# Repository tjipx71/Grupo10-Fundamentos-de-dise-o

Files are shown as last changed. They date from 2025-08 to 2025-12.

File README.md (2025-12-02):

# Equipo 10 - Fundamentos de Diseño 2025-2 
### Carrera de Ingeniería Ambiental / Informática   
**Universidad Peruana Cayetano Heredia**

---

## ENLACE DE DOCUMENTOS
https://docs.google.com/document/d/1tMh8w4P5lDI5NhleI3tkeHCaXAwBYwVb13Nxs4feQHg/edit?tab=t.0

## ENLACE DE ANTECEDENTES
LINK: https://docs.google.com/document/d/1iryDLKVLULV_mIBQmUCyinJf2zCzh2xDUNVw8ERWV84/edit?tab=t.qnuqcshna2gs

## ENLACE DE LISTA DE EXIGENCIAS
LINK: https://docs.google.com/document/d/1k8qPc2LVsW6A_ICCk7txNZ1e9gbutrCt8sIwpefmW50/edit?tab=t.0

## MODELADO 3D
LINK: https://cad.onshape.com/documents/656ee1c99e9142d88051f12c/w/5371e5df41db558604f3e5a4/e/c92471acf1fb395369bb92c8
---

## 🌍 Descripción del equipo

Somos participantes del curso **Fundamentos de Diseño 2025-2**, integrados por estudiantes de Ingeniería Ambiental y Informática. Nuestra misión es utilizar la metodología de diseño para desarrollar soluciones creativas que aporten valor social, tecnológico y ambiental.

En esta ocasión, hemos decidido centrar nuestro trabajo en el **Objetivo de Desarrollo Sostenible 6**: Agua limpia y saneamiento. Nos comprometemos a abordar desafíos relacionados con el acceso y la gestión responsable del agua, buscando generar un impacto positivo en nuestras comunidades y en el entorno natural.  

---

## Objetivo

Hacer el descarte de aguas posiblemente contaminadas con un dispositivo costo efectivo con lectura fácil y rápida, mostrando la categoría de los Estándares de Calidad del Agua para mejor comprensión y con una opción que describa los parámetros medidos. De esta manera se evita que la población use recursos hídricos comprometidos.

## Criterios de medición
- **pH:** Mide acidez/alcalinidad, clave para potabilidad y vida acuática.
- **Turbidez:** Indica partículas y posible presencia de patógenos.
- **Conductividad y salinidad:** Reflejan sales disueltas y riesgo para riego y consumo.
- **Temperatura:** Afecta solubilidad de oxígeno y actividad biológica.
- **Oxigeno disuelto:** Indican contaminación o exceso de materia orgánica en descomposición.

## Impacto esperado
- ***Social:*** Acceso a agua segura en comunidades vulnerables.
- ***Ambiental***: Reducción de enfermedades de origen hídrico y mejor control de la calidad del agua.
- ***Tecnológico:*** uso de sensores accesibles y plataformas digitales para monitoreo en tiempo real.

## Resultados esperados / métricas

- Conectar la información a un dashboard IoT.
- Posible escalabilidad hacia sistemas de alerta comunitaria o municipal
---

## 📷 Fotografía del equipo

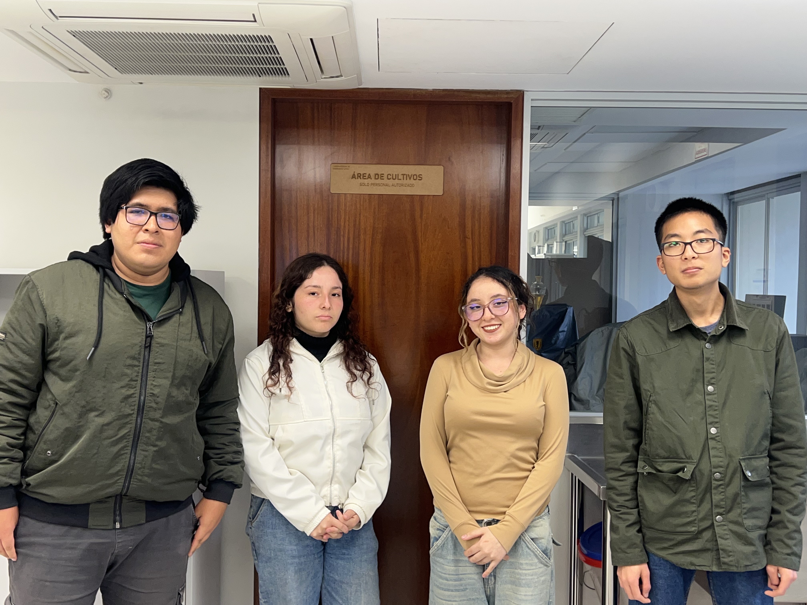
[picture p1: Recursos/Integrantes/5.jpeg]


---

## 👫 Integrantes

| Foto | Nombre | Rol | Intereses |
|---|---| --- | --- |
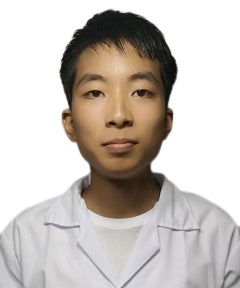
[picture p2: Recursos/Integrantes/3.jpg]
|  | **Karita John Kenneth** | **Líder / Diseñador** | **Diseño de prototipos, hardware** |
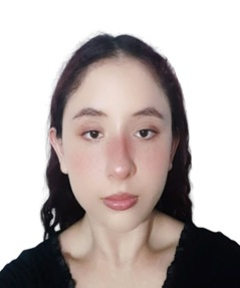
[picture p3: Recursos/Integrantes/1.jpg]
|  | **Belevan Amaro Bertha Dominik**|  **Responsable de investigación** | **Gestión ambiental, desarrollo comunitario** |
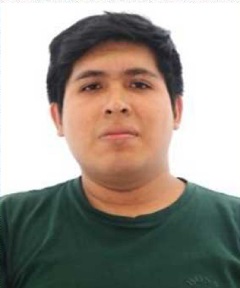
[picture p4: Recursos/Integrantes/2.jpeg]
|  | **Cctamayo Vasquez Willy Simeon** | **Programador / Modelador** | **Programación, simulación** |
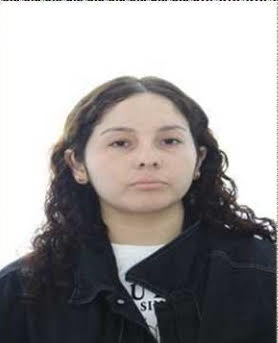
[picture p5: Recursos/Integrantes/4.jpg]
|  | **Vega Cuzcano Zulema Yamile** | **Encargado de Documentación** | **Producción de documentos científicos y técnicos** |

---

## 📚 Resumen Final
- Este README explica quiénes somos, qué nos motiva y cómo enfocamos nuestro trabajo en el **Objetivo de Desarrollo Sostenible 6: Agua limpia y saneamiento.** Somos un grupo comprometido con aprender y aportar soluciones para garantizar el acceso al agua potable y el saneamiento adecuado, fundamentales para la salud y el bienestar. Durante el curso, nuestro objetivo es contribuir a mejorar la gestión y uso sostenible del agua, buscando generar un impacto positivo en nuestra comunidad y el medio ambiente.

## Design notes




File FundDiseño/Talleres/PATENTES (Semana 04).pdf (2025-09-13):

OTRAS CATEGORÍAS

PARA SENSOR ESPECÍFICO

G01K - MEDICIÓN DE TEMPERATURA

G01R-27/22 medición de resistencia eléctrica de fluidos

G01Q-40/02 patrones de calibración

INTERPRETACIÓN DE DATOS

A62C-37/40 conexión eléctrica entre sensor y actuador

G01R-13/00 muestra de variables eléctricas

FUENTE DE PODER

E21B-47/017 protección de instrumentos

G01R-22/00 medidores de electricidad

G01R-1/03 circuitos de protección

TÍTULO | INSTRUMENTO PORTÁTIL DE MEDICIÓN DE LA CALIDAD DEL AGUA
SOLICITANTE(S) | | | FECHA DE PUBLICACIÓN
RESUMEN | | GRÁFICA/IMAGEN

BEIJING YONGCHENG TAMBIÉN CRÉDITO CIENCIA Y TECNOLOGÍA DESARROLLO SOCIEDAD LIMITADA

### 21 de junio de 2022

El modelo de utilidad pertenece al campo de los instrumentos de medición, y se refiere particularmente a un instrumento portátil de medición de calidad de agua que comprende una carcasa, un manguito antideslizante montado fijamente en un lado de la pared exterior de la carcasa, una primera ranura de fijación formada en el extremo superior de la pared exterior de la carcasa, un primer bloque de fijación conectado a la primera ranura de fijación, y un perno de fijación penetra a través del extremo superior del primer bloque de fijación; un extremo del perno de fijación está conectado con el mango; a través de la disposición del conjunto colorimétrico de muestra, una ranura de sujeción, un bloque de sujeción, una pantalla de filtro, una primera bisagra y una cubierta a prueba de polvo, se puede evitar que el líquido que se necesita medir se filtre aún más cuando el dispositivo se utiliza para la medición, se evita que las impurezas grandes entren en el dispositivo para influir en el resultado de la detección, y la pantalla de filtro se puede desmontar y limpiar después de un uso prolongado a través de la disposición de la ranura de sujeción y el bloque de sujeción, de modo que el dispositivo es cómodo de usar. Se prolonga la vida útil, se reduce el consumo de recursos y la primera bisagra y la cubierta a prueba de polvo están dispuestas de modo que el puerto de detección se puede proteger cuando el dispositivo no se utiliza y se evita que el polvo y otras impurezas ingresen al dispositivo para afectar el próximo uso.

CIP | G01N21/01, G01N21/78
LINK | https://worldwide.espacenet.com/patent/search/family/081998412/publication/CN216791993U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 water%20quality%20measuring%20instrument%22 (https://worldwide.espacenet.com/patent/search/family/081998412/publication/CN216791993U)

TITULO | Instrumento portátil de medición de la calidad del agua
SOLICITANTE(S) | | POINT FOUR WATER QUALITY TECHNOLOGIES SUZHOU CO LTDPOINT | FECHA DE PUBLICACIÓN
FOUR WATER QUALITY TECHNOLOGIES (SUZHOU) CO., LTD. 2012-01-04
RESUMEN | GRAFICA/IMAGEN

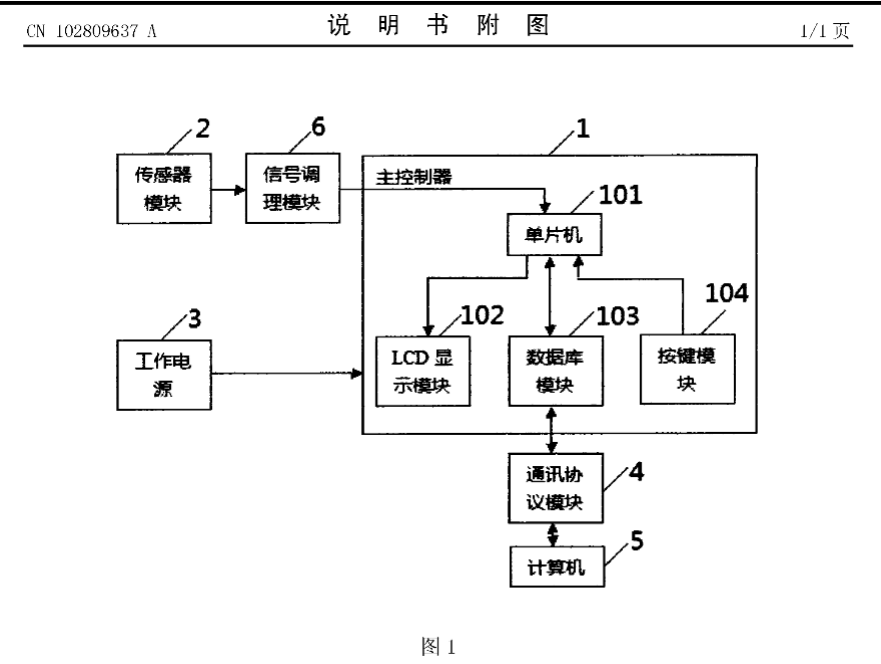
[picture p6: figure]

La invención describe un instrumento portátil de medición de la calidad del agua. El
instrumento portátil de medición de la calidad del agua comprende un controlador principal
conectado a una fuente de alimentación de funcionamiento, en donde el controlador principal comprende un solo chip y un módulo de base de datos, que están conectados entre sí; el módulo de base de datos está conectado a un módulo de protocolo de comunicación utilizado para comunicarse con una computadora; el solo chip está conectado a un módulo de modulación de señal; y el módulo de modulación de señal está conectado a un módulo de sensor. El módulo sensor incluye un sensor inteligente de conductividad/salinidad, un sensor inteligente de potencial de oxidación-reducción, un sensor inteligente de valor de pH, un sensor inteligente de gas disuelto total y un sensor inteligente de oxígeno disuelto. El instrumento portátil de medición de calidad de agua divulgado por la invención tiene las ventajas de alta precisión de medición, pequeño volumen y conveniencia para transportarlo y puede ser operado durante mucho tiempo; y los parámetros de medición de calidad de agua pueden almacenarse simultáneamente en el instrumento de medición de calidad de agua y en una computadora personal.
CIP | G01N33/18
LINK | https://worldwide.espacenet.com/patent/search/family/047233397/publication/CN102809637A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 water%20quality%20measuring%20instrument%22 (https://worldwide.espacenet.com/patent/search/family/047233397/publication/CN102809637A)

TITULO | Wireless water quality multi-parameter monitoring system
SOLICITANTE(S) | HANGZHOU ZONWON TECHNOLOGY CO LTDHANGZHOU ZONWON TECHNOLOGY CO., LTD. | FECHA DE PUBLICACION: 6 de Agosto 2014
RESUMEN | | GRAFICA/IMAGEN
La invención divulga un sistema inalámbrico de monitoreo multiparamétrico de calidad de agua que
consiste en un servidor, un terminal de usuario y una pluralidad de monitores inalámbricos
multiparamétricos de calidad de agua, en donde los monitores inalámbricos multiparamétricos de
calidad de agua están conectados con el servidor a través de una red de comunicación inalámbrica, y el terminal de usuario está conectado con el servidor a través de una red de comunicación cableada o inalámbrica; el software de gestión de datos y un módulo receptor inalámbrico están instalados en el servidor, y las baterías, las placas de circuitos de control, los módulos transmisores inalámbricos y los sensores de calidad de agua están instalados en las carcasas de los monitores inalámbricos multiparamétricos de calidad de agua. Según este sistema, no es necesario que un trabajador mida o tome muestras en el sitio, por lo que el costo de mano de obra se reduce en gran medida y, además, se pueden proporcionar datos en tiempo real, de modo que la calidad del agua se pueda dominar de manera conveniente y completa en tiempo real.
CIP | G01N33/18

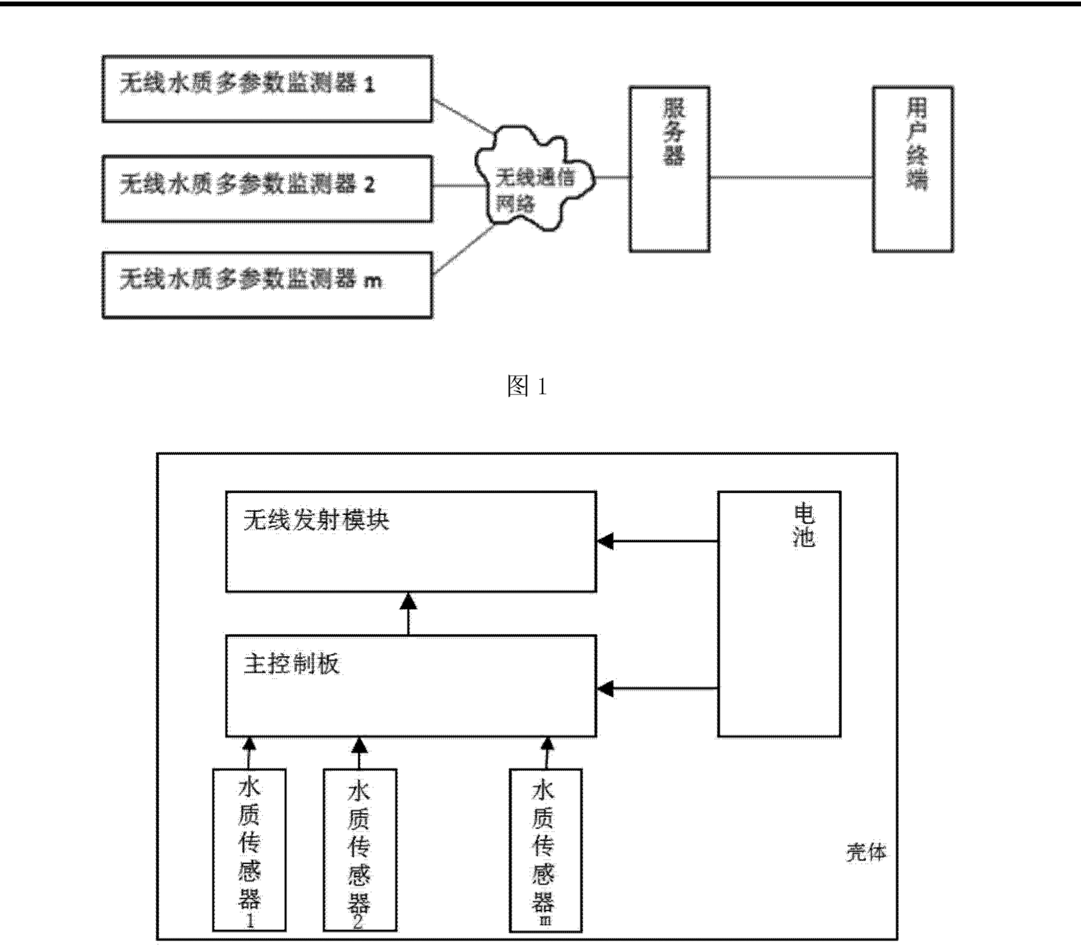
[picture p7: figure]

LINK | https://worldwide.espacenet.com/patent/search/family/051239164/publication/CN103969414A?q=ti%20all%20%22Wirele ss%20multi-parameter%20water-quality%20monitoring%20system%22 (https://worldwide.espacenet.com/patent/search/family/051239164/publication/CN103969414A)

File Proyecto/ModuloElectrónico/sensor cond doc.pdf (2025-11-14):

Documentación del sensor de conductividad

Para obtener el valor de una resistencia desconocida se le puede aplicar un voltaje conocido y éste como resultado tendrá un consumo medible. Debido a que los Convertidores Digitales Analógicos (ADC) no pueden medir intensidad, se le tiene que poner una resistencia de valor conocido en serie con la resistencia desconocida para poder formar un divisor de voltaje y con su salida calcular el valor de la resistencia que se desea saber.

Este mismo principio se utiliza para el sensor de conductividad del agua, puesto a que la conductividad es la inversa de la resistencia dividido por la distancia entre electrodos. Pero, tiene un detalle muy importante, el voltaje de medición tiene que ser alterna y su voltaje pulsante tiene que ser lo suficientemente bajo como para no alterar las propiedades del agua mediante electrólisis.

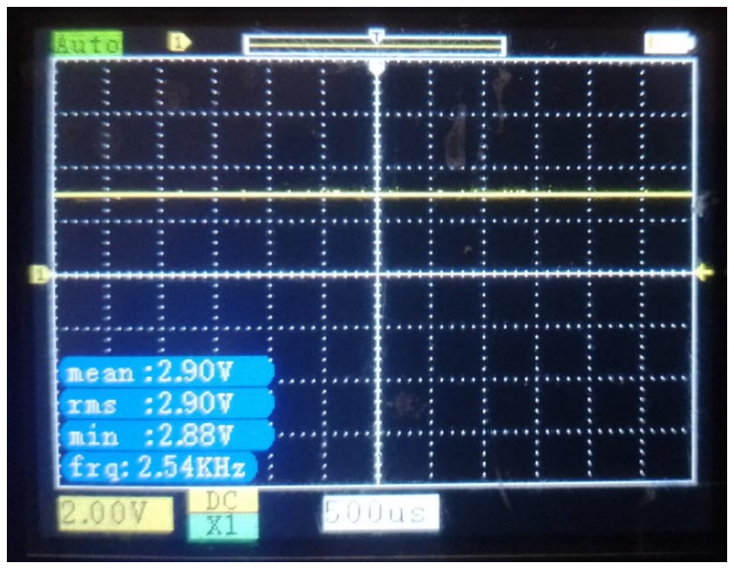
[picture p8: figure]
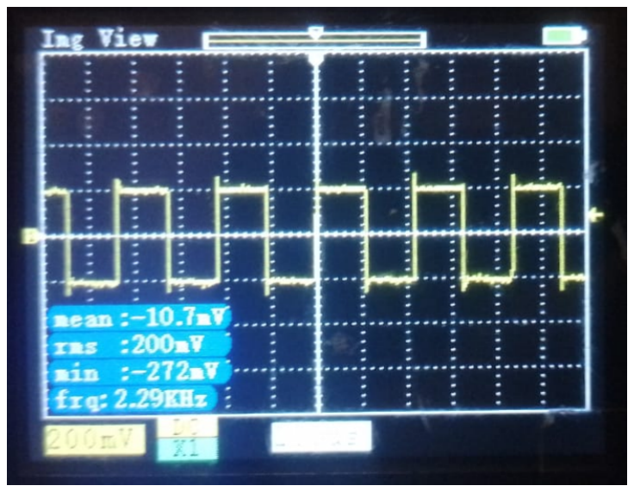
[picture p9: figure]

Multímetro | Sensor de TDS/Conductividad

Para lograr el primer efecto se puede utilizar un controlador que genere una señal, el problema viene cuando sus señales digitales son de 0V a 5V, no de -0.2V a 0.2V. Con el fin de resolver este problema, se podría utilizar un divisor de voltaje y un amplificador operacional configurado como seguidor de voltaje. Inmediatamente viene otro problema, la alimentación de 5V al controlador no ofrece voltajes negativos. Esto se puede solucionar utilizando un divisor de voltaje para obtener 2.5V y mandando su salida a un seguidor de voltaje para que éste ofrezca un voltaje de referencia al primer amplificador operacional. Con esto, se puede utilizar el primer amplificador operacional para generar 2.7V y 2.3V con respecto a GND, cuyas lecturas respecto al voltaje de referencia (2.5V) sería de 0.2V y -0.2V.

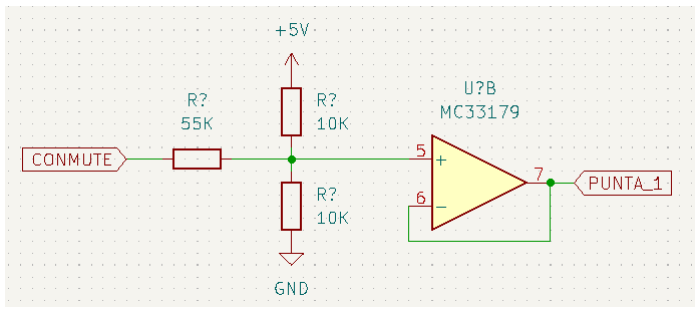
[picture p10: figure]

Generador de pulsos apoyado por microcontrolador en el pin “Conmutar”

Voltaje de referencia

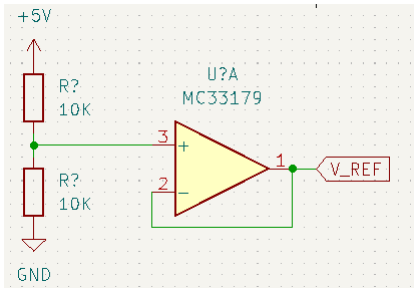
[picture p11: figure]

Teniendo ya la señal de pulsos que va a un electrodo y un voltaje de referencia, se puede medir construyendo un divisor de voltaje compuesto por una resistencia de valor conocido y el agua a medir, utilizando las señales previamente mencionadas. Debido a que la diferencia de potencial es mínima y se desea medir con buen precisión, éste debe amplificarse dentro del rango permitido de voltajes (-2.5V a 2.5V con respecto a referencia).

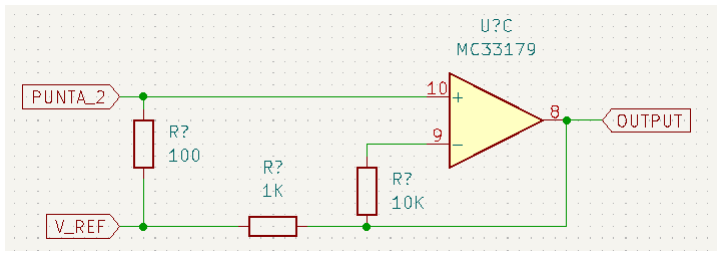
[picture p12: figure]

Nótese que la “punta 1” y “punta 2” son los pines de los electrodos que van al agua.

Para la lectura por parte de un microcontrolador, éste debe tener en cuenta los siguientes pines:

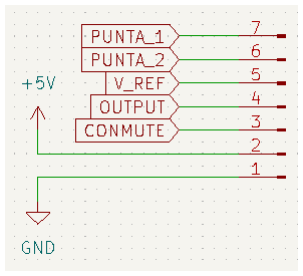
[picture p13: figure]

El código para leer la conductividad del agua para el controlador Arduino Nano:

#include <LiquidCrystal.h>

// LCD pins <--> Arduino pins

const | | int | RS = | 11, EN = | 12, D4 = | 2, D5 = | 3, D6 = | 4, D7 = | 5;
LiquidCrystal | lcd(RS, EN, D4, D5, D6, D7);
const | | float | r = | 100;
void | setup()
{
lcd.begin(16, | 2); | // set up number of columns and rows
pinMode(6, OUTPUT);
}
float | | leer(){
float | av_out = | analogRead(A0);
float | av_ref = | analogRead(A1);
float | av_pul = | analogRead(A2);
float | v_out = av_out/1023;
float | v_ref = av_ref/1023;
float | v_pul = av_pul/1023;
float | v_read = | (v_out - v_ref)/11;
float | v_pulse = v_pul - v_ref;
float | r_water = | (r * | (v_pulse - v_read)/v_read);
return | r_water;
}

void loop()
{
float | sum = | 0;
int | a = | 0;
while(a != | | | 500){
digitalWrite(6, HIGH);
sum = sum + | leer();
delayMicroseconds(500);
digitalWrite(6, LOW);
sum = sum + | leer();
delayMicroseconds(500);
a = a + | 1;
}
float | conductivity = | 0;
conductivity = | 1000000000 | / sum;

lcd.clear();
lcd.setCursor(0, | | | | 0);
lcd.print("Conductividad:");
lcd.setCursor(0, | | | | 1);
if(conductivity < | | 100){
lcd.print("< 100 uS");
} | else | | if | (conductivity > | 8000){

lcd.print("> 8000 uS");
} | else | if | (100 | <= conductivity and conductivity <= | 8000){
lcd.print(conductivity);
lcd.print(" uS");
} | else | {
lcd.print("Averiado");
}
}

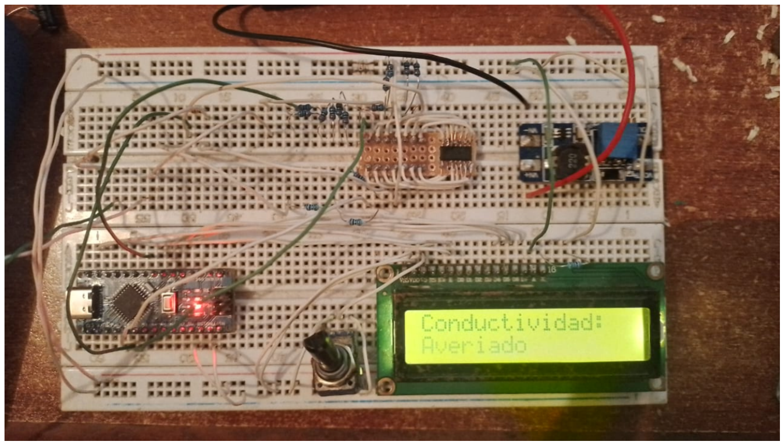
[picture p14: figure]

Construcción en placa de prototipo, el MC33179 fue adaptado de SMD a THT.

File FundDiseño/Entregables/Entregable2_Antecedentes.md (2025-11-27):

OTRAS CATEGORÍAS

PARA SENSOR ESPECÍFICO

G01K \- MEDICIÓN DE TEMPERATURA

G01R-27/22 medición de resistencia eléctrica de fluidos

G01Q-40/02 patrones de calibración

INTERPRETACIÓN DE DATOS

A62C-37/40 conexión eléctrica entre sensor y actuador

G01R-13/00 muestra de variables eléctricas

FUENTE DE PODER

E21B-47/017 protección de instrumentos

G01R-22/00 medidores de electricidad

G01R-1/03 circuitos de protección

| TÍTULO |  INSTRUMENTO PORTÁTIL DE MEDICIÓN DE LA CALIDAD DEL AGUA |  |
| :---- | ----- | ----- |
| **SOLICITANTE(S)** |  BEIJING YONGCHENG TAMBIÉN CRÉDITO CIENCIA Y TECNOLOGÍA DESARROLLO SOCIEDAD LIMITADA | **FECHA DE PUBLICACIÓN 21 de junio de 2022** |

| | |
| :---- | ----- |
| **RESUMEN** | **GRÁFICA/IMAGEN** |
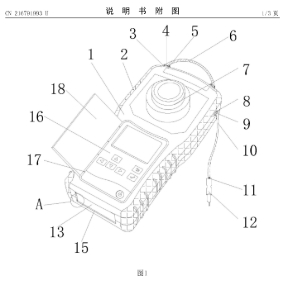
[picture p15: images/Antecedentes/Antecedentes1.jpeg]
|  El modelo de utilidad pertenece al campo de los instrumentos de medición, y se refiere particularmente a un instrumento portátil de medición de calidad de agua que comprende una carcasa, un manguito antideslizante montado fijamente en un lado de la pared exterior de la carcasa, una primera ranura de fijación formada en el extremo superior de la pared exterior de la carcasa, un primer bloque de fijación conectado a la primera ranura de fijación, y un perno de fijación penetra a través del extremo superior del primer bloque de fijación; un extremo del perno de fijación está conectado con el mango; a través de la disposición del conjunto colorimétrico de muestra, una ranura de sujeción, un bloque de sujeción, una pantalla de filtro, una primera bisagra y una cubierta a prueba de polvo, se puede evitar que el líquido que se necesita medir se filtre aún más cuando el dispositivo se utiliza para la medición, se evita que las impurezas grandes entren en el dispositivo para influir en el resultado de la detección, y la pantalla de filtro se puede desmontar y limpiar después de un uso prolongado a través de la disposición de la ranura de sujeción y el bloque de sujeción, de modo que el dispositivo es cómodo de usar. Se prolonga la vida útil, se reduce el consumo de recursos y la primera bisagra y la cubierta a prueba de polvo están dispuestas de modo que el puerto de detección se puede proteger cuando el dispositivo no se utiliza y se evita que el polvo y otras impurezas ingresen al dispositivo para afectar el próximo uso. |  |
| **CIP** | G01N21/01, G01N21/78 |

| | |
| :---- | ----- |
| **LINK** | [https://worldwide.espacenet.com/patent/search/family/081998412/publication/CN216791993U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](https://worldwide.espacenet.com/patent/search/family/081998412/publication/CN216791993U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)  |

| TÍTULO | Instrumento portátil de medición de la calidad del agua |  |
| :---- | :---- | :---- |
| **SOLICITANTE(S)** | POINT FOUR WATER QUALITY TECHNOLOGIES SUZHOU CO LTDPOINT FOUR WATER QUALITY TECHNOLOGIES (SUZHOU) CO., LTD. | **FECHA DE PUBLICACIÓN** 2012-01-04 |

| | |
| :---- | ----- |
| **RESUMEN** |  | **GRÁFICA/IMAGEN** |
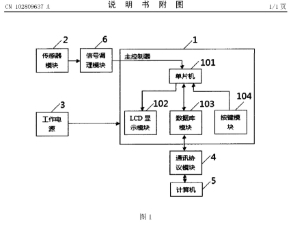
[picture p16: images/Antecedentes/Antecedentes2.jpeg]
|  La invención describe un instrumento portátil de medición de la calidad del agua. El instrumento portátil de medición de la calidad del agua comprende un controlador principal conectado a una fuente de alimentación de funcionamiento, en donde el controlador principal comprende un solo chip y un módulo de base de datos, que están conectados entre sí; el módulo de base de datos está conectado a un módulo de protocolo de comunicación utilizado para comunicarse con una computadora; el solo chip está conectado a un módulo de modulación de señal; y el módulo de modulación de señal está conectado a un módulo de sensor. El módulo sensor incluye un sensor inteligente de conductividad/salinidad, un sensor inteligente de potencial de oxidación-reducción, un sensor inteligente de valor de pH, un sensor inteligente de gas disuelto total y un sensor inteligente de oxígeno disuelto. El instrumento portátil de medición de calidad de agua divulgado por la invención tiene las ventajas de alta precisión de medición, pequeño volumen y conveniencia para transportarlo y puede ser operado durante mucho tiempo; y los parámetros de medición de calidad de agua pueden almacenarse simultáneamente en el instrumento de medición de calidad de agua y en una computadora personal.  |  |
| **CIP** | G01N33/18 .|  

| | |
| :---- | ----- |
| **LINK** | [https://worldwide.espacenet.com/patent/search/family/047233397/publication/CN102809637A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](https://worldwide.espacenet.com/patent/search/family/047233397/publication/CN102809637A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) |  

| TÍTULO | Wireless water quality multi-parameter monitoring system |  |
| :---- | :---- | :---- |
| **SOLICITANTE(S)** | HANGZHOU ZONWON TECHNOLOGY CO LTDHANGZHOU ZONWON TECHNOLOGY CO., LTD. | **FECHA DE PUBLICACIÓN: 6 de Agosto 2014** |

| | |
| :---- | ----- |
| **RESUMEN** |  | **GRÁFICA/IMAGEN** |
| La invención divulga un sistema inalámbrico de monitoreo multiparamétrico de calidad de agua que consiste en un servidor, un terminal de usuario y una pluralidad de monitores inalámbricos multiparamétricos de calidad de agua, en donde los monitores inalámbricos multiparamétricos de calidad de agua están conectados con el servidor a través de una red de comunicación inalámbrica, y el terminal de usuario está conectado con el servidor a través de una red de comunicación cableada o inalámbrica; el software de gestión de datos y un módulo receptor inalámbrico están instalados en el servidor, y las baterías, las placas de circuitos de control, los módulos transmisores inalámbricos y los sensores de calidad de agua están instalados en las carcasas de los monitores inalámbricos multiparamétricos de calidad de agua. Según este sistema, no es necesario que un trabajador mida o tome muestras en el sitio, por lo que el costo de mano de obra se reduce en gran medida y, además, se pueden proporcionar datos en tiempo real, de modo que la calidad del agua se pueda dominar de manera conveniente y completa en tiempo real.  |  |
| **CIP** | G01N33/18 .|  

| | |
| :---- | ----- |
| **LINK** | [https://worldwide.espacenet.com/patent/search/family/051239164/publication/CN103969414A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](https://worldwide.espacenet.com/patent/search/family/051239164/publication/CN103969414A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) |

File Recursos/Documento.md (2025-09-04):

ODS 6 : Agua limpia y saneamiento

El estudio sobre el monitoreo de la calidad del agua en un lago costero poco profundo destaca la aplicación de sistemas de información geográfica (SIG) junto con técnicas de análisis de decisiones multicriterio para mejorar significativamente la evaluación espacial de los parámetros ambientales. Esta combinación de herramientas permite un análisis más detallado y preciso de la distribución y variabilidad de la calidad del agua, facilitando una toma de decisiones más informada y efectiva para la gestión ambiental del ecosistema acuático. Así, el uso integrado de SIG y métodos multicriterio representa un avance importante en la planificación y conservación de cuerpos de agua sensibles, optimizando los recursos y promoviendo prácticas sostenibles. (1)

El propósito de investigar técnicas de análisis de decisiones multicriterio es observar las limitaciones de los sensores que posiblemente se añadan al proyecto (PH, sólidos disueltos, turbidez y conductividad) comparado a una situación ideal de medición. También, verificar los pesos de cada criterio y formular un posible índice tomando en cuenta los pocos parámetros que se pueden obtener sin sobrepasar el presupuesto.

El 33.33% de las mujeres evaluadas presentaron niveles elevados de mercurio en muestras de cabello, lo que indica una exposición significativa a este contaminante. Aunque no se encontró una correlación estadísticamente significativa entre la concentración de mercurio y la edad de las participantes, se observó que la mayoría de estas mujeres desempeñan labores domésticas y mantienen una dieta habitual basada en el consumo de pescado. Este patrón alimenticio sugiere que la principal vía de exposición al mercurio es a través de la ingesta continua de productos pesqueros, lo que pone en evidencia un riesgo crónico para la salud asociado a la acumulación de metales pesados provenientes del entorno ambiental y la cadena alimentaria. (2)

El estudio que desentraña y comprende las percepciones locales sobre la calidad del agua en la cuenca del Santa, Perú, resulta fundamental para captar cómo las comunidades perciben, valoran y responden a los riesgos asociados con la contaminación hídrica. Este enfoque sociocultural permite identificar barreras y oportunidades en la comunicación ambiental, facilitando así la implementación de estrategias más efectivas de prevención, educación y gestión del recurso hídrico, adaptadas a las realidades y necesidades locales. (3)

El estudio sobre la dinámica de la calidad del agua del río Cunas en zonas rurales y urbanas de la región central del Perú aporta datos valiosos y detallados acerca de las variaciones espaciales y temporales de los parámetros físico-químicos del agua. Esta información es fundamental para identificar diferencias significativas en los niveles de contaminación entre distintas áreas, lo que a su vez permite evaluar los posibles riesgos asociados para la salud humana y la integridad del ecosistema. Gracias a estos hallazgos, se pueden diseñar estrategias de gestión y mitigación más efectivas para proteger los recursos hídricos y garantizar un suministro seguro para las comunidades que dependen de este río.(4)

La Tabla 1 presenta los valores de concentración de indicadores fisicoquímicos —como pH, oxígeno disuelto, conductividad y sólidos totales— medidos en diferentes años en el río Cunas, Perú. Estos datos evidencian la variabilidad temporal en la calidad del agua y permiten identificar posibles riesgos para la salud pública y el ambiente. (5)

El estudio sobre acuicultura sostenible presenta un sistema integrado basado en tecnologías IoT que permite el monitoreo en tiempo real de la calidad del agua. Gracias al uso de sensores avanzados para medir parámetros críticos como el oxígeno disuelto y el amoníaco, este sistema facilita una gestión eficiente y oportuna, mejorando el control de las condiciones ambientales necesarias para el desarrollo saludable de los cultivos acuícolas. (6)

La revisión sobre contaminación del agua y evaluación de parámetros de calidad ofrece una visión clara de los principales indicadores físico-químicos usados para evaluar el estado de los cuerpos de agua. Permite entender tanto los niveles de contaminantes como su impacto en la salud ecológica y humana. Además, destaca la importancia de monitorear continuamente variables como pH, oxígeno disuelto, conductividad y sólidos totales, información clave para la toma de decisiones ambientales y el manejo sostenible de los recursos hídricos.(7)

Referencias	

1.	Batina A, Šiljeg A. Enhancing water quality monitoring in a coastal shallow lake using GIS and multi-criteria decision analysis. Environ Sustain Indic. diciembre de 2025;28:100881. 
2.	Grandez-Urbina JA, Gonzalo-Rodríguez J, Ronceros-Mayorga V, Bedoya-Vidal S, Grandez-Castillo G, Pérez-Zárate C. Concentración de mercurio en cabello de mujeres en una comunidad nativa de Perú. Gac Sanit. 1 de marzo de 2014;28(2):177. 
3.	Rangecroft S, Dextre RM, Richter I, Grados Bueno CV, Kelly C, Turin C, et al. Unravelling and understanding local perceptions of water quality in the Santa basin, Peru. J Hydrol. 1 de octubre de 2023;625:129949. 
4.	Custodio M, Peñaloza R, Chanamé F, Hinostroza-Martínez JL, De la Cruz H. Water quality dynamics of the Cunas River in rural and urban areas in the central region of Peru. Egypt J Aquat Res. 1 de septiembre de 2021;47(3):253-9. 
5.	Data on the spatial and temporal variability of physical-chemical water quality indicators of the Cunas River, Peru. Chem Data Collect. 1 de junio de 2021;33:100672. 
6.	Zuhaer A, Khandoker A, Enayet N, Partha PKP, Awal MdA. Sustainable Aquaculture: An IoT-Integrated System for Real-Time Water Quality Monitoring Featuring Advanced DO and Ammonia Sensors. Aquac Eng. 2 de septiembre de 2025;102620. 
7.	Water pollution and the assessment of water quality parameters: a review. Desalination Water Treat. 1 de mayo de 2023;294:79-88.

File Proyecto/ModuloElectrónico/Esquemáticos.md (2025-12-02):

## ESQUEMÁTICO INICIAL
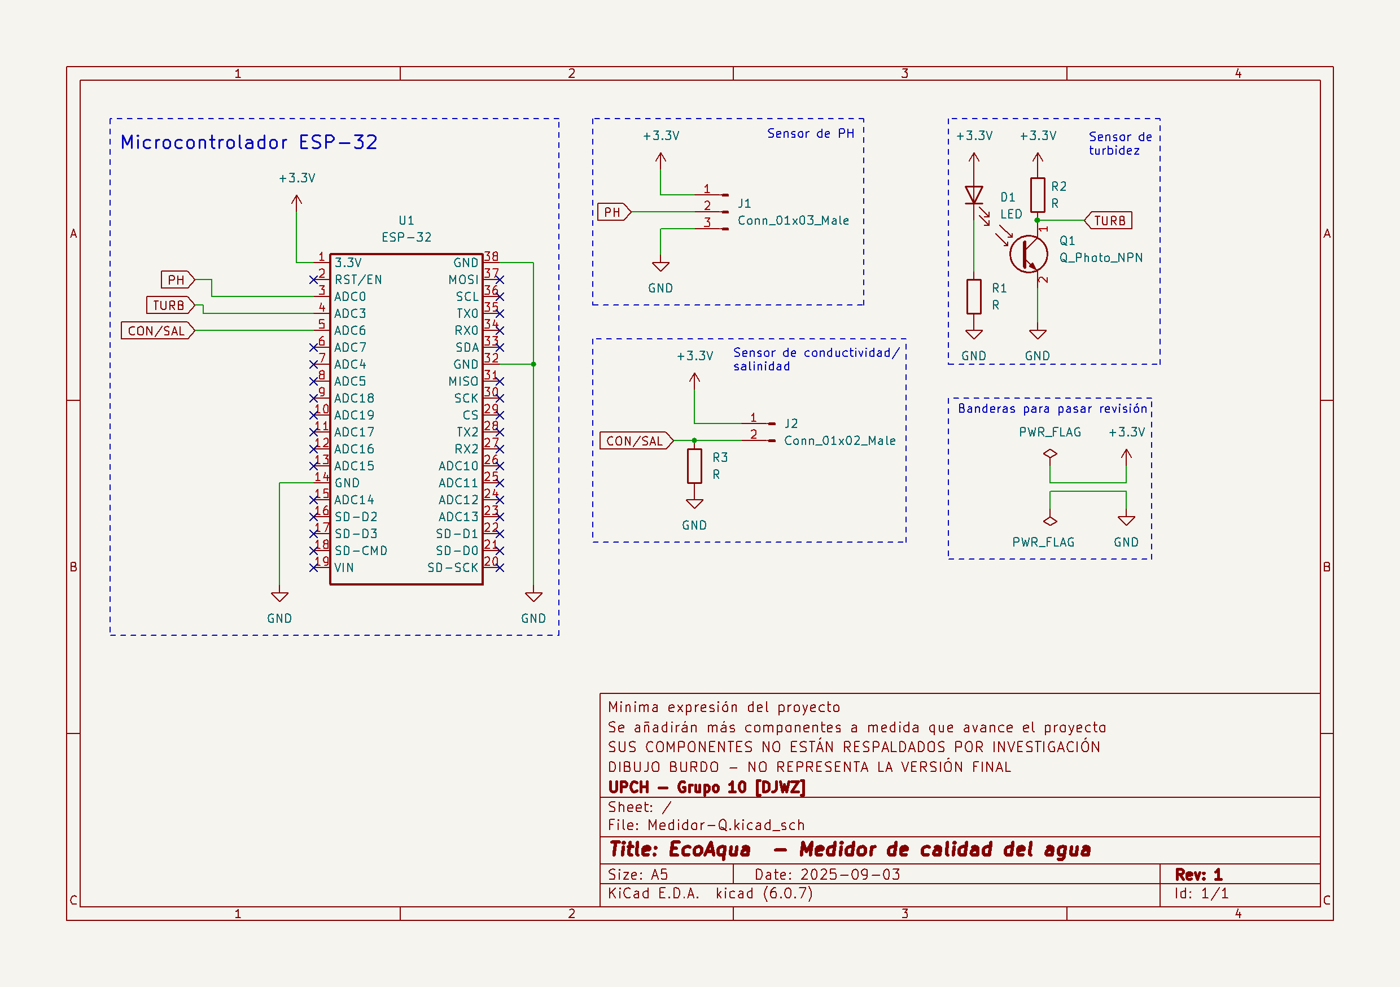
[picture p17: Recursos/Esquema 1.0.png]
 

## ESQUEMÁTICO DEL DISPOSITIVO DE DO + TEMP

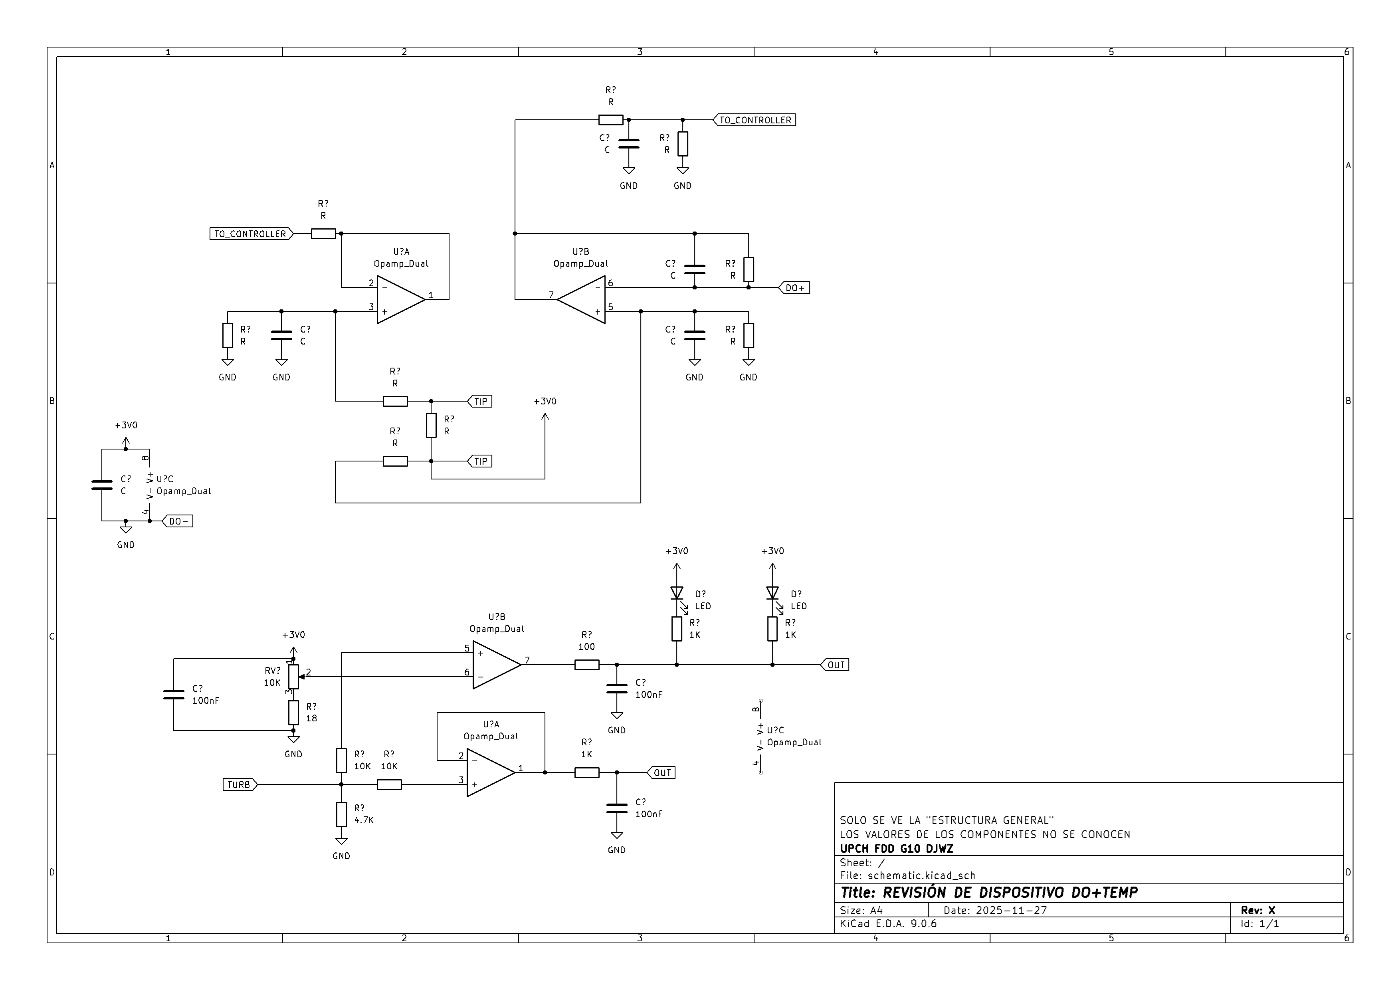
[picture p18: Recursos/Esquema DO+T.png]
 

## ESQUEMÁTICO FINAL

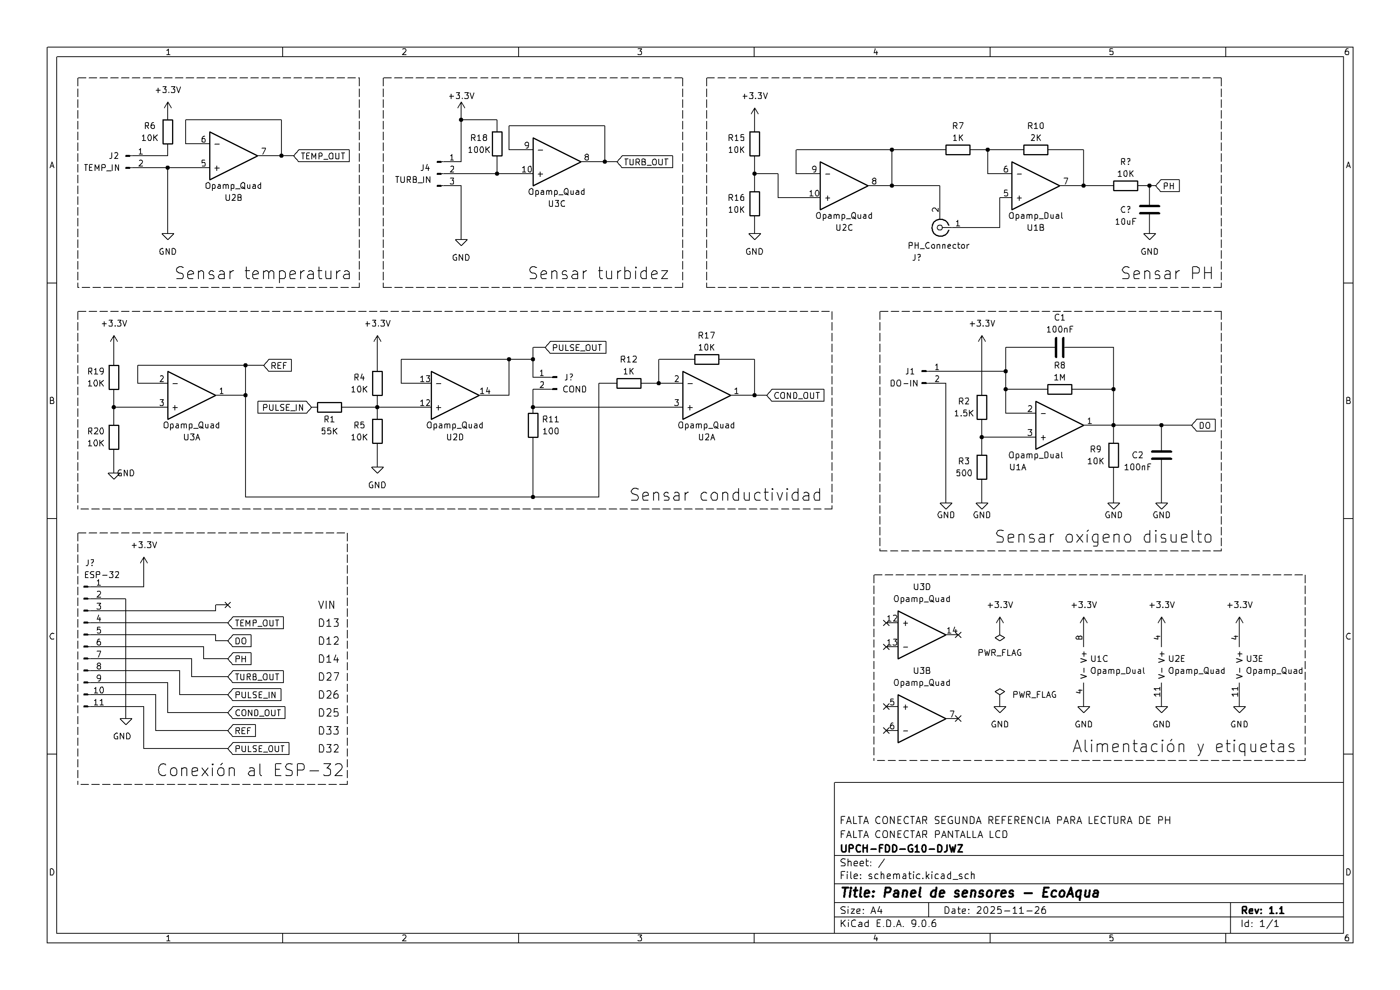
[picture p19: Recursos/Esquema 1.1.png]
 

## FINAL DEL ARCHIVO

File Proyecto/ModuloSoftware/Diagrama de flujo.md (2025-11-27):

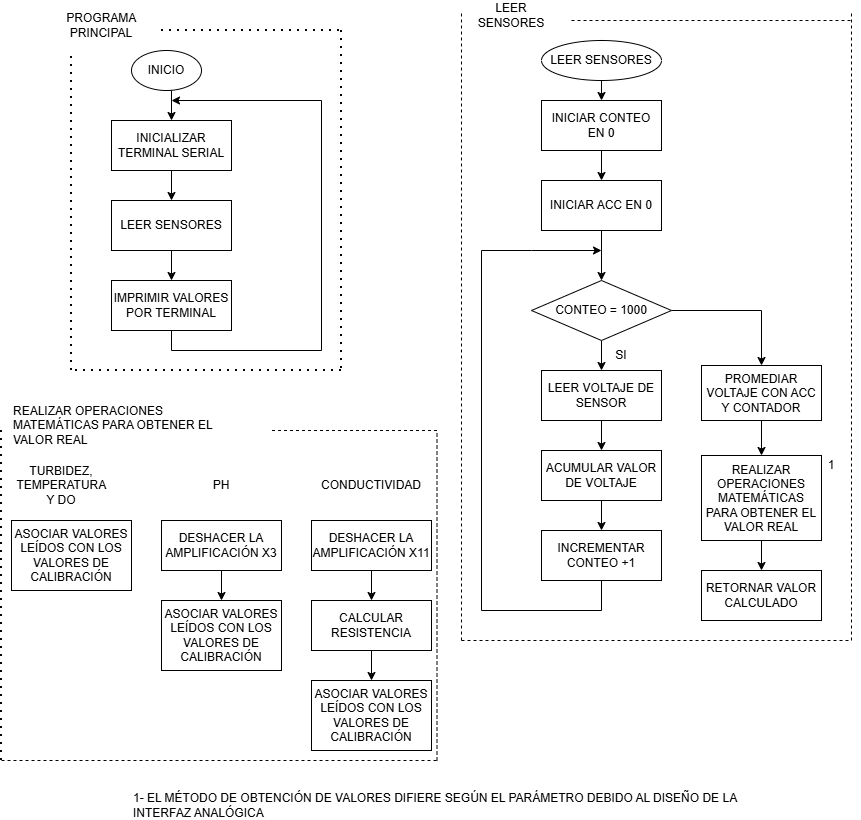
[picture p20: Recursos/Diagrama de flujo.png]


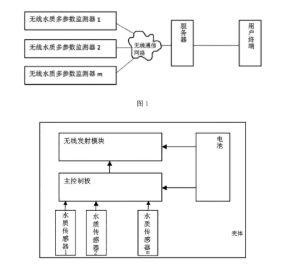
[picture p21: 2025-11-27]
images/Antecedentes/Antecedentes3.jpeg

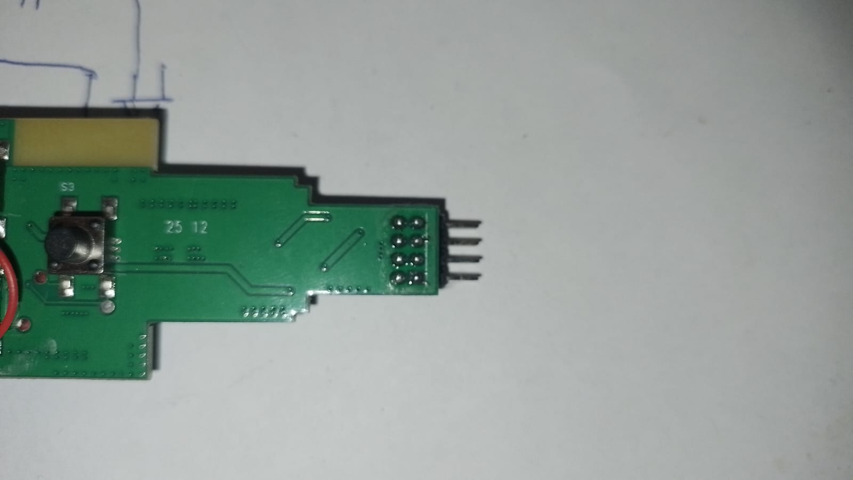
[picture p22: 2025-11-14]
Proyecto/ModuloElectrónico/Ingeniería inversa DO + Temp/DO PCB back.jpeg

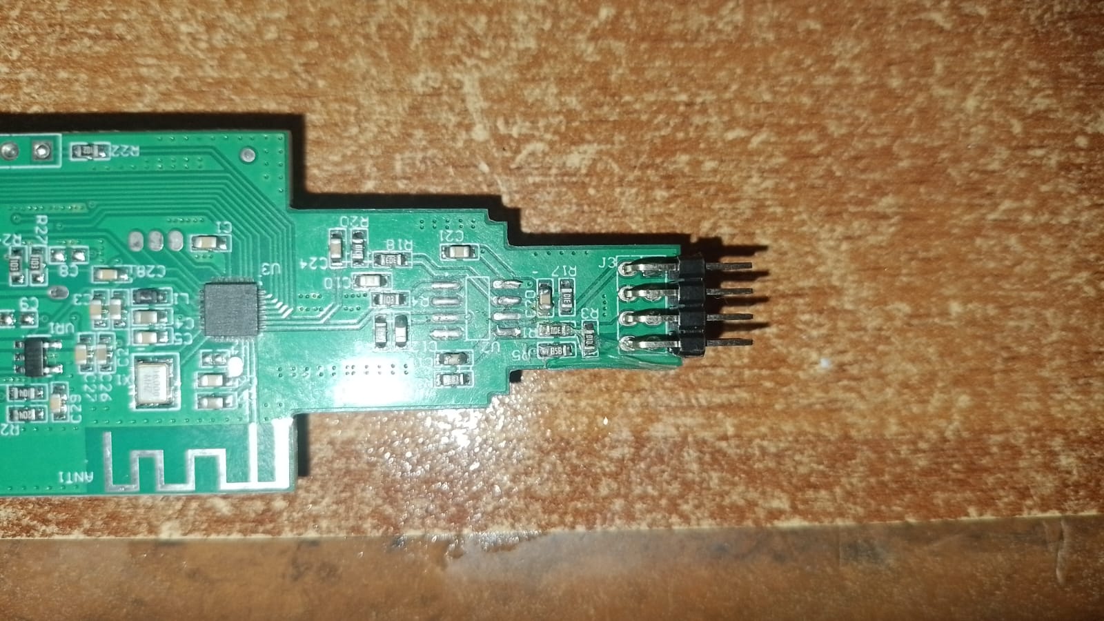
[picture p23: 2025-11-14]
Proyecto/ModuloElectrónico/Ingeniería inversa DO + Temp/DO PCB front.jpeg

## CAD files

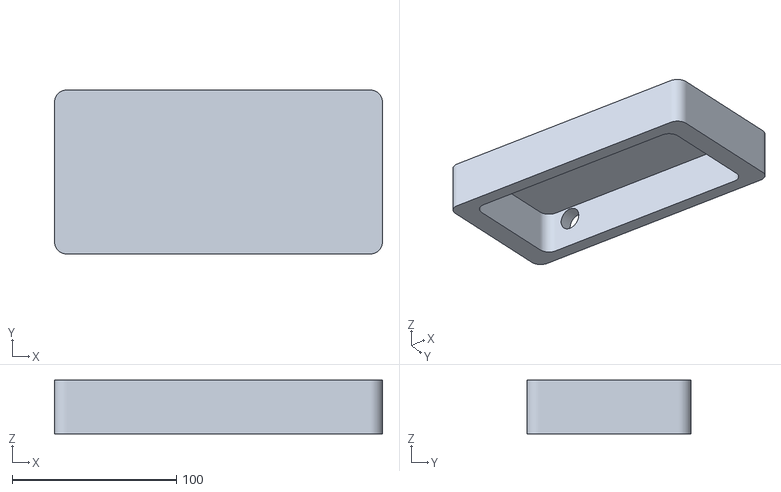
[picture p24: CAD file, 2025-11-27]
Proyecto/ModuloMecánico/Ensamblaje - Carcasa.stl
200.0 x 100.0 x 32.9

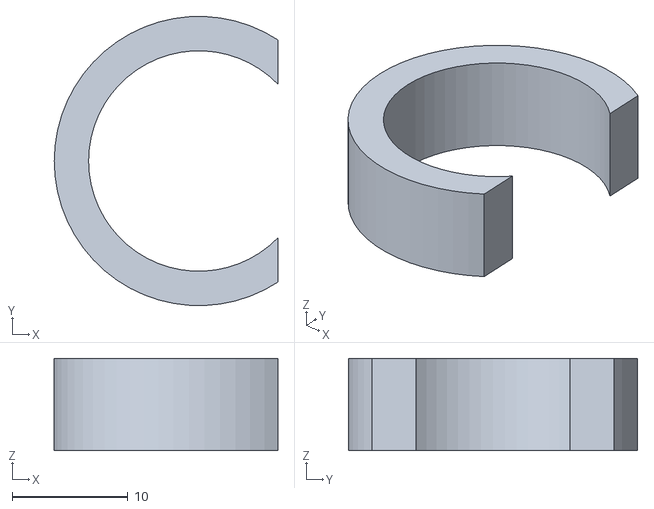
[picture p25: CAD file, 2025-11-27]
Proyecto/ModuloMecánico/Ensamblaje - Ganchos.stl
19.3 x 25.0 x 8.00

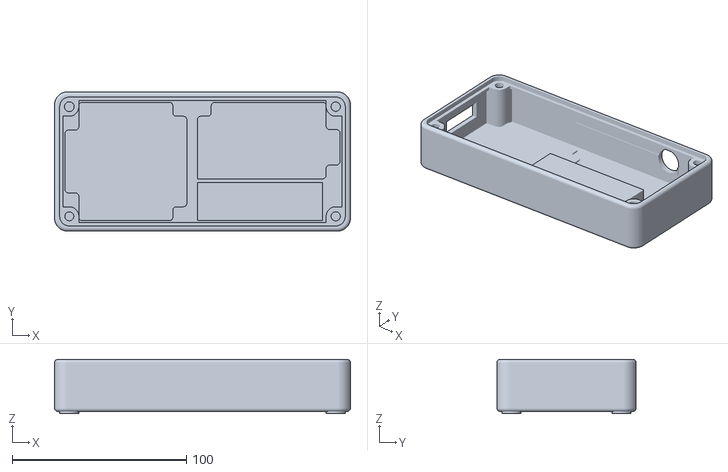
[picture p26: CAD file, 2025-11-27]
Proyecto/ModuloMecánico/Ensamblaje - Base.stl
170.0 x 80.0 x 31.2

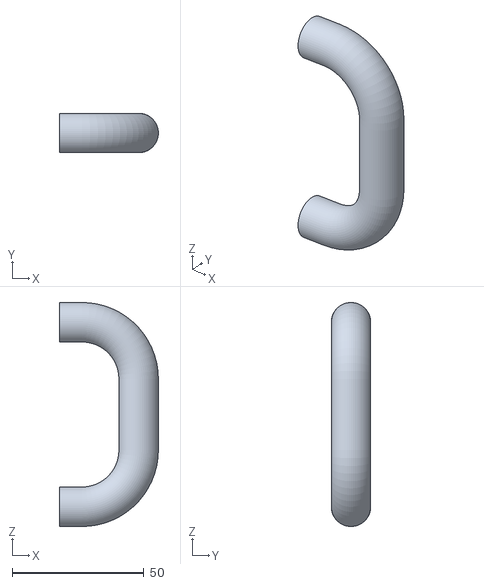
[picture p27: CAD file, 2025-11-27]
Proyecto/ModuloMecánico/Ensamblaje - Manijas.stl
37.5 x 15.0 x 85.0

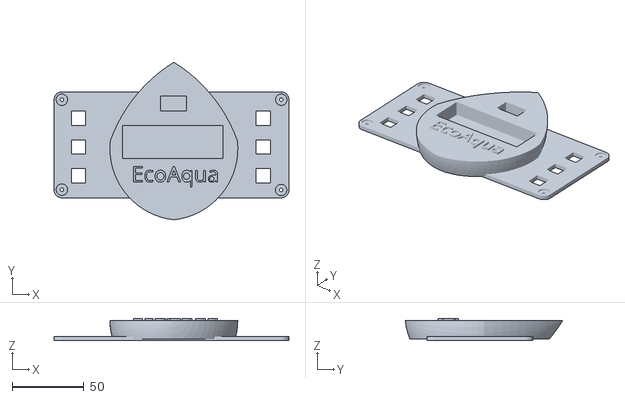
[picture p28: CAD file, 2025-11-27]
Proyecto/ModuloMecánico/Ensamblaje - Tapa.stl
164.0 x 110.0 x 15.5

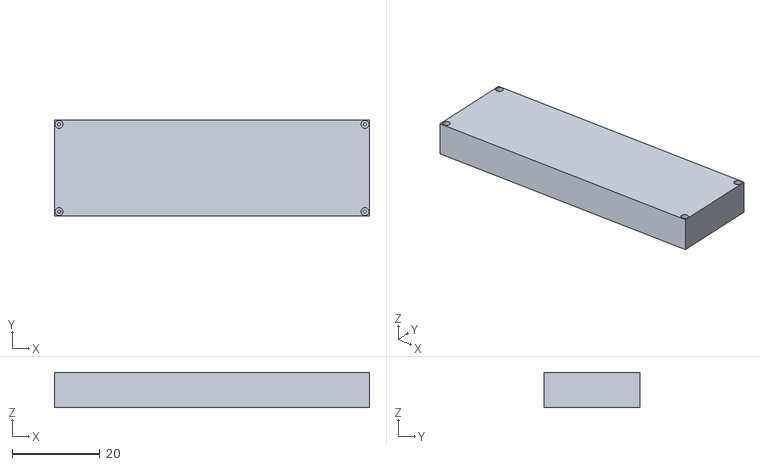
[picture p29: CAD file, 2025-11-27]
Proyecto/ModuloMecánico/Ensamblaje -Tapa bateria.stl
72.0 x 22.0 x 8.00

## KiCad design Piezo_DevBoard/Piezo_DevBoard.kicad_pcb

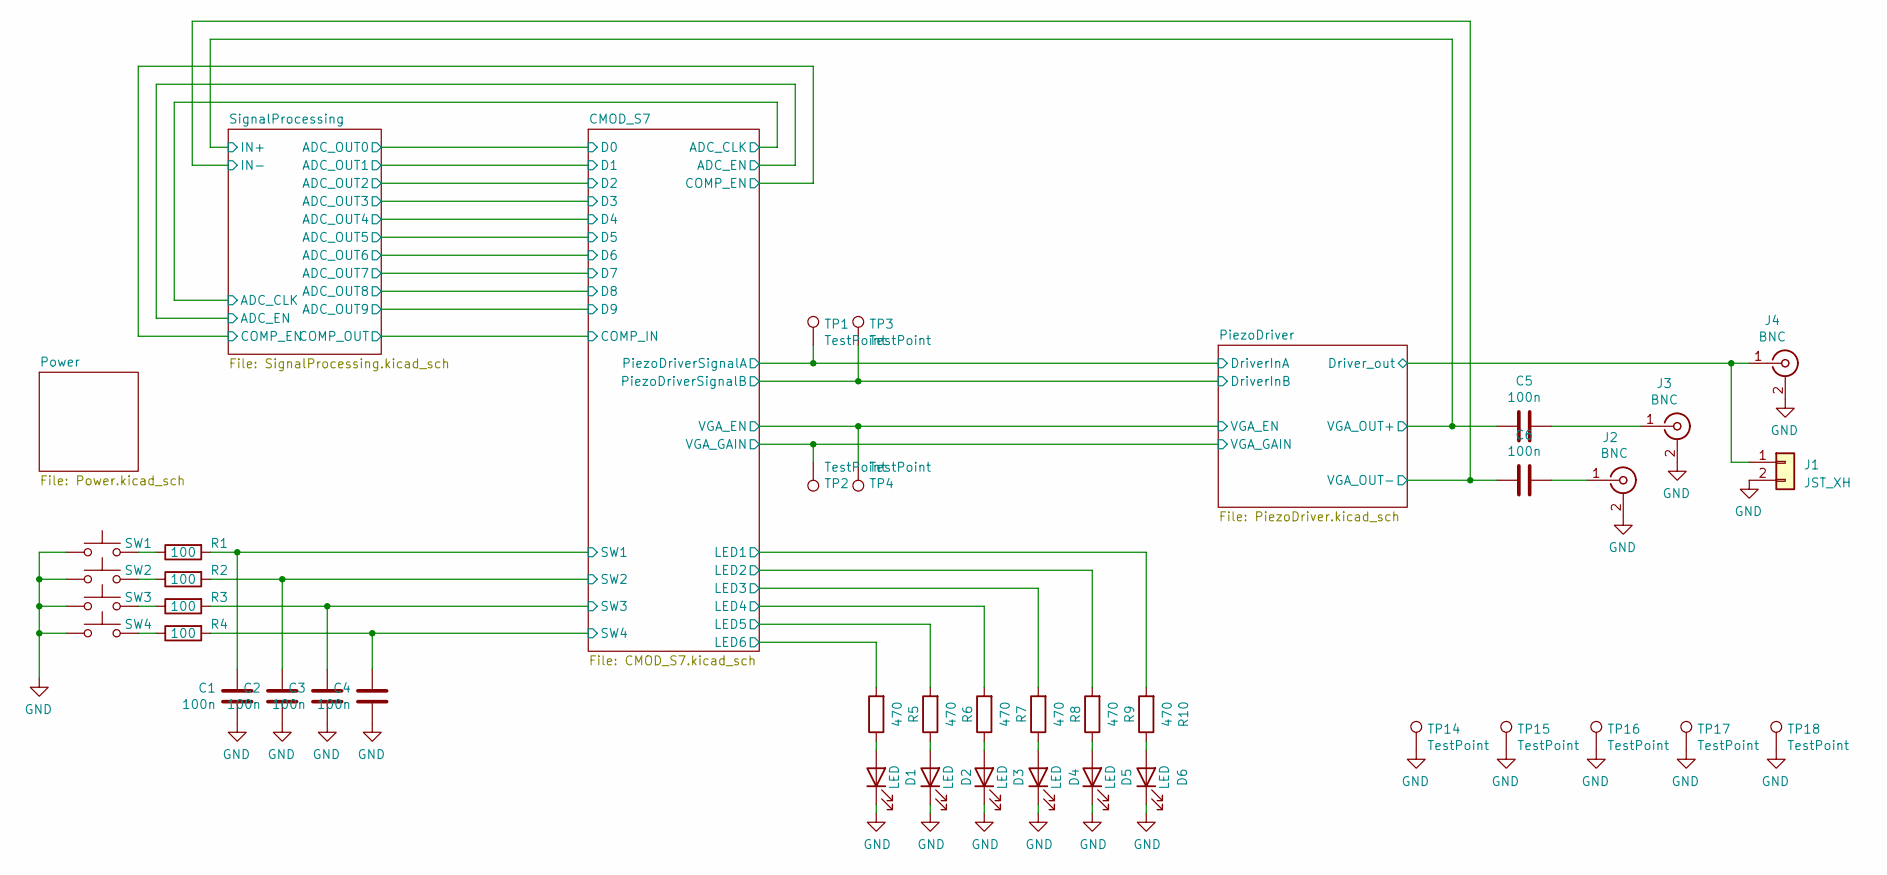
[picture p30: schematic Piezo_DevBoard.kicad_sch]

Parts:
C1, C2, C3, C4, C5, C6: 100n; C_0603_1608Metric_Pad1.08x0.95mm_HandSolder
D1, D2, D3, D4, D5, D6: LED; LED_0805_2012Metric_Pad1.15x1.40mm_HandSolder
J1: JST_XH; JST_XH_B2B-XH-A_1x02_P2.50mm_Vertical
J2, J3, J4: BNC; BNC_Amphenol_B6252HB-NPP3G-50_Horizontal
R1, R2, R3, R4: 100; R_0603_1608Metric_Pad0.98x0.95mm_HandSolder
R5, R6, R7, R8, R9, R10: 470; R_0603_1608Metric_Pad0.98x0.95mm_HandSolder
SW1, SW2, SW3, SW4: SW_Push; SW_Push_1P1T_NO_6x6mm_H9.5mm
TP1, TP2, TP3, TP4, TP14, TP15, TP16, TP17, TP18: TestPoint; TestPoint_Loop_D1.80mm_Drill1.0mm_Beaded

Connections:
/CMOD_S7/LED1: R10.2; also elsewhere on the board
/CMOD_S7/LED2: R9.2; also elsewhere on the board
/CMOD_S7/LED3: R8.2; also elsewhere on the board
/CMOD_S7/LED4: R7.2; also elsewhere on the board
/CMOD_S7/LED5: R6.2; also elsewhere on the board
/CMOD_S7/LED6: R5.2; also elsewhere on the board
/CMOD_S7/PiezoDriverSignalA: TP1.1; also elsewhere on the board
/CMOD_S7/PiezoDriverSignalB: TP3.1; also elsewhere on the board
/CMOD_S7/SW1: C1.1, R1.2; also elsewhere on the board
/CMOD_S7/SW2: C2.1, R2.2; also elsewhere on the board
/CMOD_S7/SW3: C3.1, R3.2; also elsewhere on the board
/CMOD_S7/SW4: C4.1, R4.2; also elsewhere on the board
/CMOD_S7/VGA_EN: TP4.1; also elsewhere on the board
/CMOD_S7/VGA_GAIN: TP2.1; also elsewhere on the board
/PiezoDriver/Driver_out: J1.1, J4.1 (In); also elsewhere on the board
/PiezoDriver/VGA_OUT+: C5.2; also elsewhere on the board
/PiezoDriver/VGA_OUT-: C6.2; also elsewhere on the board
GND: C1.2, C2.2, C3.2, C4.2, D1.1 (K), D2.1 (K), D3.1 (K), D4.1 (K), D5.1 (K), D6.1 (K), J1.2, J2.2 (Ext), J3.2 (Ext), J4.2 (Ext), SW1.2, SW2.2, SW3.2, SW4.2, TP14.1, TP15.1, TP16.1, TP17.1, TP18.1; also elsewhere on the board
unnamed: C5.1, J3.1 (In)
unnamed: C6.1, J2.1 (In)
unnamed: D1.2 (A), R5.1
unnamed: D2.2 (A), R6.1
unnamed: D3.2 (A), R7.1
unnamed: D4.2 (A), R8.1
unnamed: D5.2 (A), R9.1
unnamed: D6.2 (A), R10.1
unnamed: R1.1, SW1.1
unnamed: R2.1, SW2.1
unnamed: R3.1, SW3.1
unnamed: R4.1, SW4.1

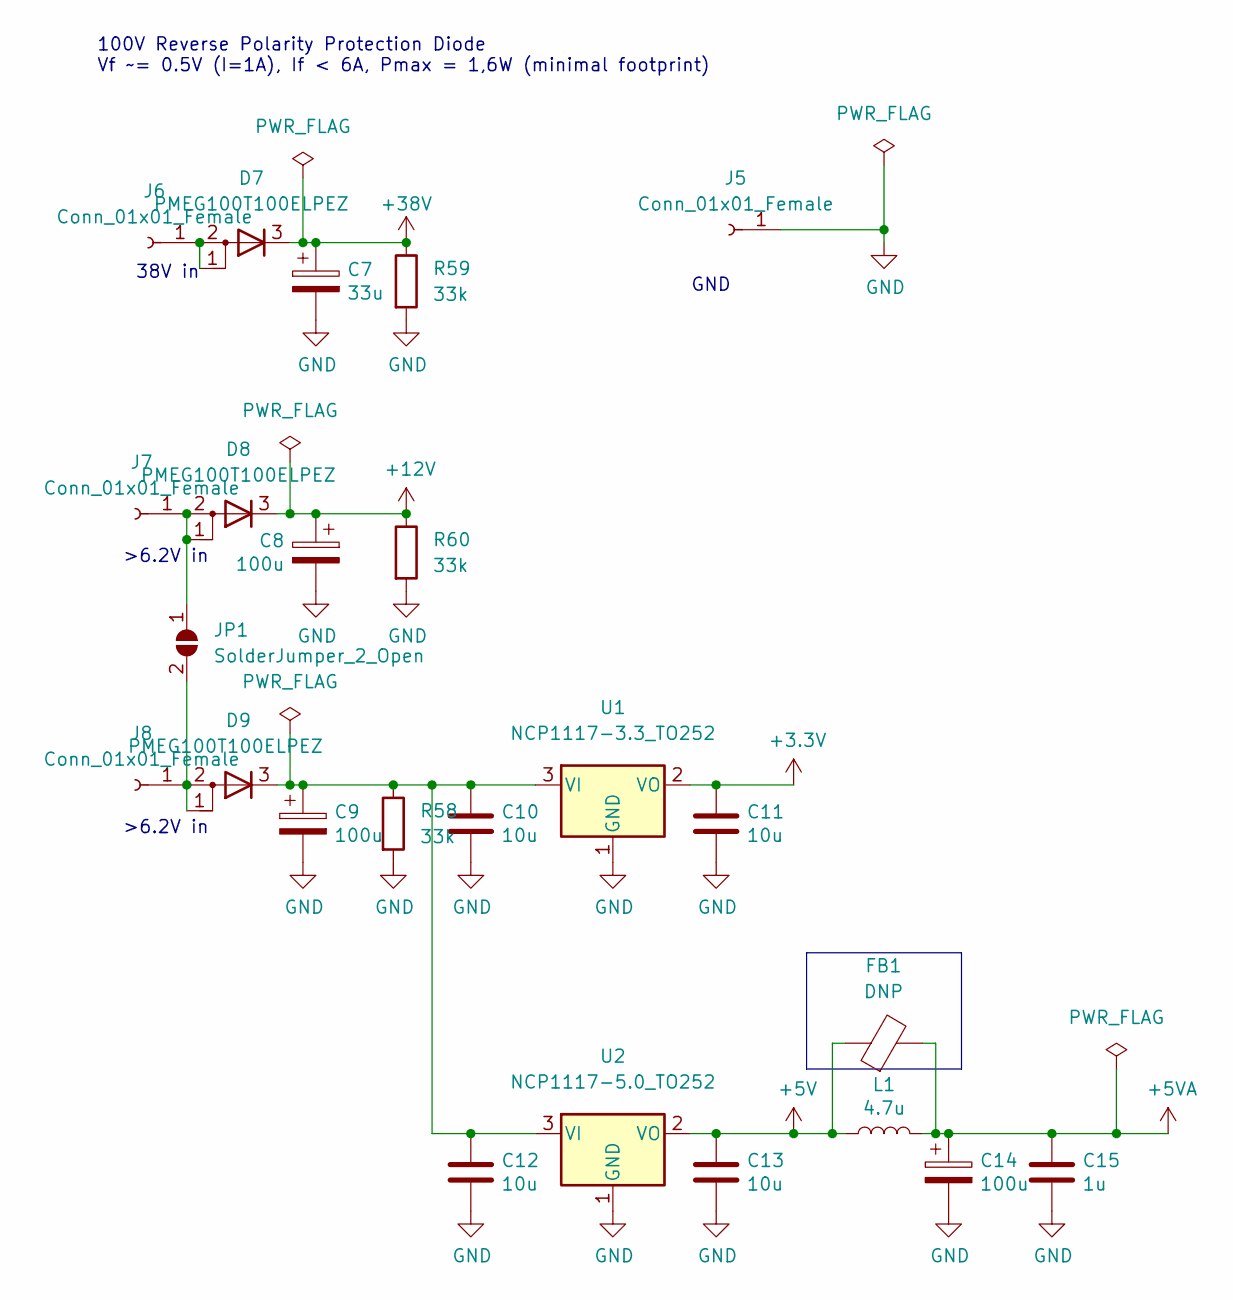
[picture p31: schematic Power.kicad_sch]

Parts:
C7: 33u; CP_Elec_10x10.5
C8, C9, C14: 100u; CP_Elec_6.3x7.7
C10, C11, C12, C13: 10u; C_0805_2012Metric_Pad1.18x1.45mm_HandSolder
C15: 1u; C_0603_1608Metric_Pad1.08x0.95mm_HandSolder
D7, D8, D9: PMEG100T100ELPEZ; Nexperia_CFP15_SOT-1289
FB1: DNP; L_0603_1608Metric_Pad1.05x0.95mm_HandSolder
J5, J6, J7, J8: Conn_01x01_Female; BananaJack_24.243
JP1: SolderJumper_2_Open; SolderJumper-2_P1.3mm_Open_TrianglePad1.0x1.5mm
L1: 4.7u; L_Wuerth_MAPI-4030
R58, R59, R60: 33k; R_1206_3216Metric_Pad1.30x1.75mm_HandSolder
U1: NCP1117-3.3_TO252; TO-252-2
U2: NCP1117-5.0_TO252; TO-252-2

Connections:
+3.3V: C11.1, U1.2 (VO); also elsewhere on the board
+5V: C13.1, FB1.1, L1.1, U2.2 (VO); also elsewhere on the board
+5VA: C14.1, C15.1, FB1.2, L1.2; also elsewhere on the board
+12V: C8.1, D8.3 (K), R60.1; also elsewhere on the board
+38V: C7.1, D7.3 (K), R59.1; also elsewhere on the board
GND: C7.2, C8.2, C9.2, C10.2, C11.2, C12.2, C13.2, C14.2, C15.2, J5.1, R58.2, R59.2, R60.2, U1.1 (GND), U2.1 (GND); also elsewhere on the board
unnamed: C9.1, C10.1, C12.1, D9.3 (K), R58.1, U1.3 (VI), U2.3 (VI)
unnamed: D7.1 (A), D7.2 (A), J6.1
unnamed: D8.1 (A), D8.2 (A), J7.1, JP1.1 (A)
unnamed: D9.1 (A), D9.2 (A), J8.1, JP1.2 (B)

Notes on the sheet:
38V in
>6.2V in
GND
100V Reverse Polarity Protection Diode Vf ~= 0.5V (I=1A), If < 6A, Pmax = 1,6W (minimal footprint)

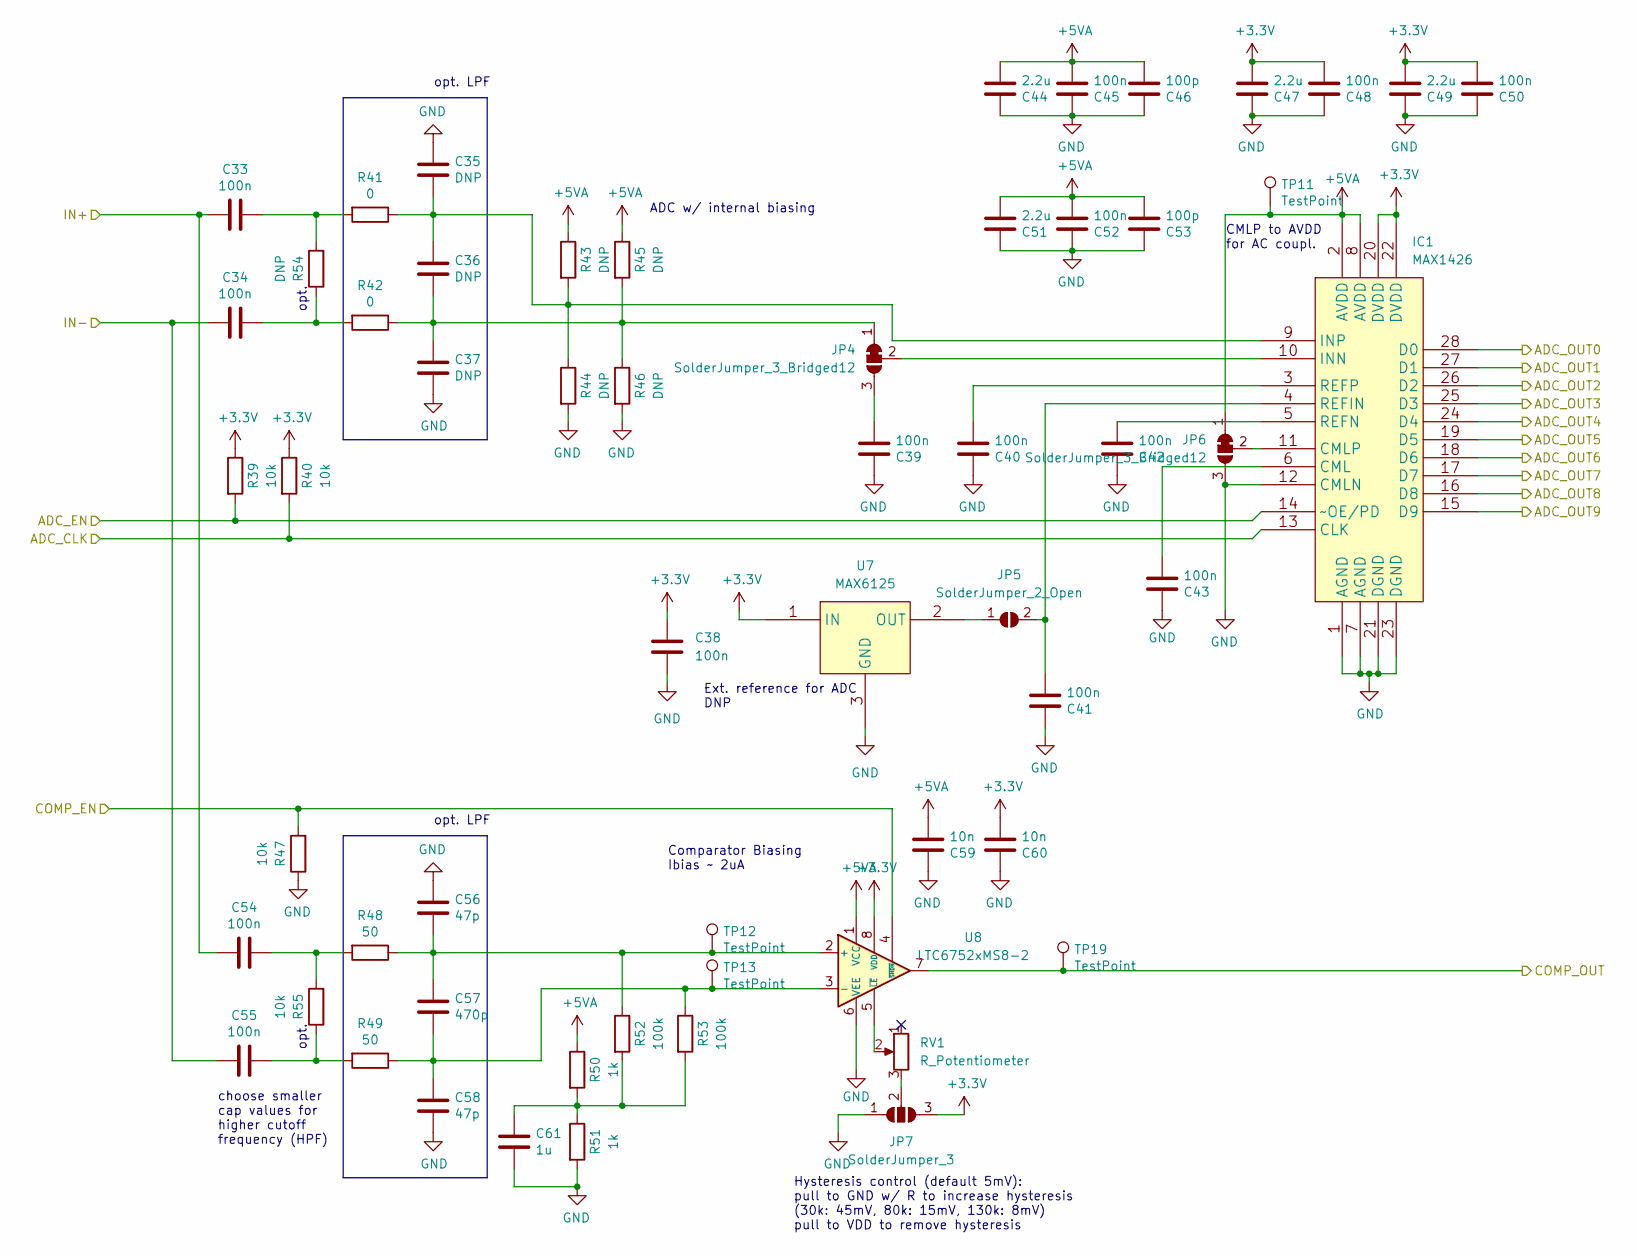
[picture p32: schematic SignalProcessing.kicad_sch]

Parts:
C33, C34, C38, C39, C40, C41, C42, C43, C45, C48, C50, C52, C54, C55: 100n; C_0603_1608Metric_Pad1.08x0.95mm_HandSolder
C35, C36, C37: DNP; C_0603_1608Metric_Pad1.08x0.95mm_HandSolder
C44, C47, C49, C51: 2.2u; C_0603_1608Metric_Pad1.08x0.95mm_HandSolder
C46, C53: 100p; C_0603_1608Metric_Pad1.08x0.95mm_HandSolder
C56, C58: 47p; C_0603_1608Metric_Pad1.08x0.95mm_HandSolder
C57: 470p; C_0603_1608Metric_Pad1.08x0.95mm_HandSolder
C59, C60: 10n; C_0603_1608Metric_Pad1.08x0.95mm_HandSolder
C61: 1u; C_0603_1608Metric_Pad1.08x0.95mm_HandSolder
IC1: MAX1426; SSOP-28_5.3x10.2mm_P0.65mm
JP4, JP6: SolderJumper_3_Bridged12; SolderJumper-3_P1.3mm_Bridged12_RoundedPad1.0x1.5mm
JP5: SolderJumper_2_Open; SolderJumper-2_P1.3mm_Open_RoundedPad1.0x1.5mm
JP7: SolderJumper_3; SolderJumper-3_P1.3mm_Open_RoundedPad1.0x1.5mm
R39, R40, R47, R55: 10k; R_0603_1608Metric_Pad0.98x0.95mm_HandSolder
R41, R42: 0; R_0603_1608Metric_Pad0.98x0.95mm_HandSolder
R43, R44, R45, R46, R54: DNP; R_0603_1608Metric_Pad0.98x0.95mm_HandSolder
R48, R49: 50; R_0603_1608Metric_Pad0.98x0.95mm_HandSolder
R50, R51: 1k; R_0603_1608Metric_Pad0.98x0.95mm_HandSolder
R52, R53: 100k; R_0603_1608Metric_Pad0.98x0.95mm_HandSolder
RV1: R_Potentiometer; Potentiometer_Bourns_3009P_Horizontal
TP11, TP12, TP13, TP19: TestPoint; TestPoint_Loop_D1.80mm_Drill1.0mm_Beaded
U7: MAX6125; SOT-23
U8: LTC6752xMS8-2; MSOP-8_3x3mm_P0.65mm

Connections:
+3.3V: C38.1, C47.2, C48.2, C49.2, C50.2, C60.2, IC1.20 (DVDD), IC1.22 (DVDD), JP7.3 (B), R39.1, R40.1, U7.1 (IN), U8.8 (VDD); also elsewhere on the board
+5VA: C44.2, C45.2, C46.2, C51.2, C52.2, C53.2, C59.2, IC1.2 (AVDD), IC1.8 (AVDD), JP6.1 (A), R43.1, R45.1, R50.1, TP11.1, U8.1 (VCC); also elsewhere on the board
/CMOD_S7/ADC_CLK: IC1.13 (CLK), R40.2; also elsewhere on the board
/CMOD_S7/ADC_EN: IC1.14 (~OE/PD), R39.2; also elsewhere on the board
/CMOD_S7/COMP_EN: R47.2, U8.4 (~SHDN); also elsewhere on the board
/CMOD_S7/COMP_IN: TP19.1, U8.7; also elsewhere on the board
/CMOD_S7/D0: IC1.28 (D0); also elsewhere on the board
/CMOD_S7/D1: IC1.27 (D1); also elsewhere on the board
/CMOD_S7/D2: IC1.26 (D2); also elsewhere on the board
/CMOD_S7/D3: IC1.25 (D3); also elsewhere on the board
/CMOD_S7/D4: IC1.24 (D4); also elsewhere on the board
/CMOD_S7/D5: IC1.19 (D5); also elsewhere on the board
/CMOD_S7/D6: IC1.18 (D6); also elsewhere on the board
/CMOD_S7/D7: IC1.17 (D7); also elsewhere on the board
/CMOD_S7/D8: IC1.16 (D8); also elsewhere on the board
/CMOD_S7/D9: IC1.15 (D9); also elsewhere on the board
/PiezoDriver/VGA_OUT+: C33.2, C54.2; also elsewhere on the board
/PiezoDriver/VGA_OUT-: C34.2, C55.2; also elsewhere on the board
GND: C35.1, C37.2, C38.2, C39.1, C40.1, C41.1, C42.1, C43.1, C44.1, C45.1, C46.1, C47.1, C48.1, C49.1, C50.1, C51.1, C52.1, C53.1, C56.1, C58.2, C59.1, C60.1, C61.2, IC1.1 (AGND), IC1.7 (AGND), IC1.12 (CMLN), IC1.21 (DGND), IC1.23 (DGND), JP6.3 (B), JP7.1 (A), R44.2, R46.2, R47.1, R51.2, U7.3 (GND), U8.6 (VEE); also elsewhere on the board
unnamed: C33.1, R41.2, R54.2
unnamed: C34.1, R42.2, R54.1
unnamed: C35.2, C36.1, IC1.9 (INP), R41.1, R43.2, R44.1
unnamed: C36.2, C37.1, JP4.1 (A), R42.1, R45.2, R46.1
unnamed: C39.2, JP4.3 (B)
unnamed: C40.2, IC1.3 (REFP)
unnamed: C41.2, IC1.4 (REFIN), JP5.2 (B)
unnamed: C42.2, IC1.5 (REFN)
unnamed: C43.2, IC1.6 (CML)
unnamed: C54.1, R48.2, R55.2
unnamed: C55.1, R49.2, R55.1
unnamed: C56.2, C57.1, R48.1, R52.1, TP12.1, U8.2 (+)
unnamed: C57.2, C58.1, R49.1, R53.1, TP13.1, U8.3 (-)
unnamed: C61.1, R50.2, R51.1, R52.2, R53.2
unnamed: IC1.10 (INN), JP4.2 (C)
unnamed: IC1.11 (CMLP), JP6.2 (C)
unnamed: JP5.1 (A), U7.2 (OUT)
unnamed: JP7.2 (C), RV1.3
unnamed: RV1.2, U8.5 (~LE)

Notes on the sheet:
opt. LPF
ADC w/ internal biasing
CMLP to AVDD for AC coupl.
opt.
Ext. reference for ADC DNP
Hysteresis control (default 5mV): pull to GND w/ R to increase hysteresis (30k: 45mV, 80k: 15mV, 130k: 8mV) pull to VDD to remove hysteresis
choose smaller cap values for higher cutoff frequency (HPF)
Comparator Biasing Ibias ~ 2uA

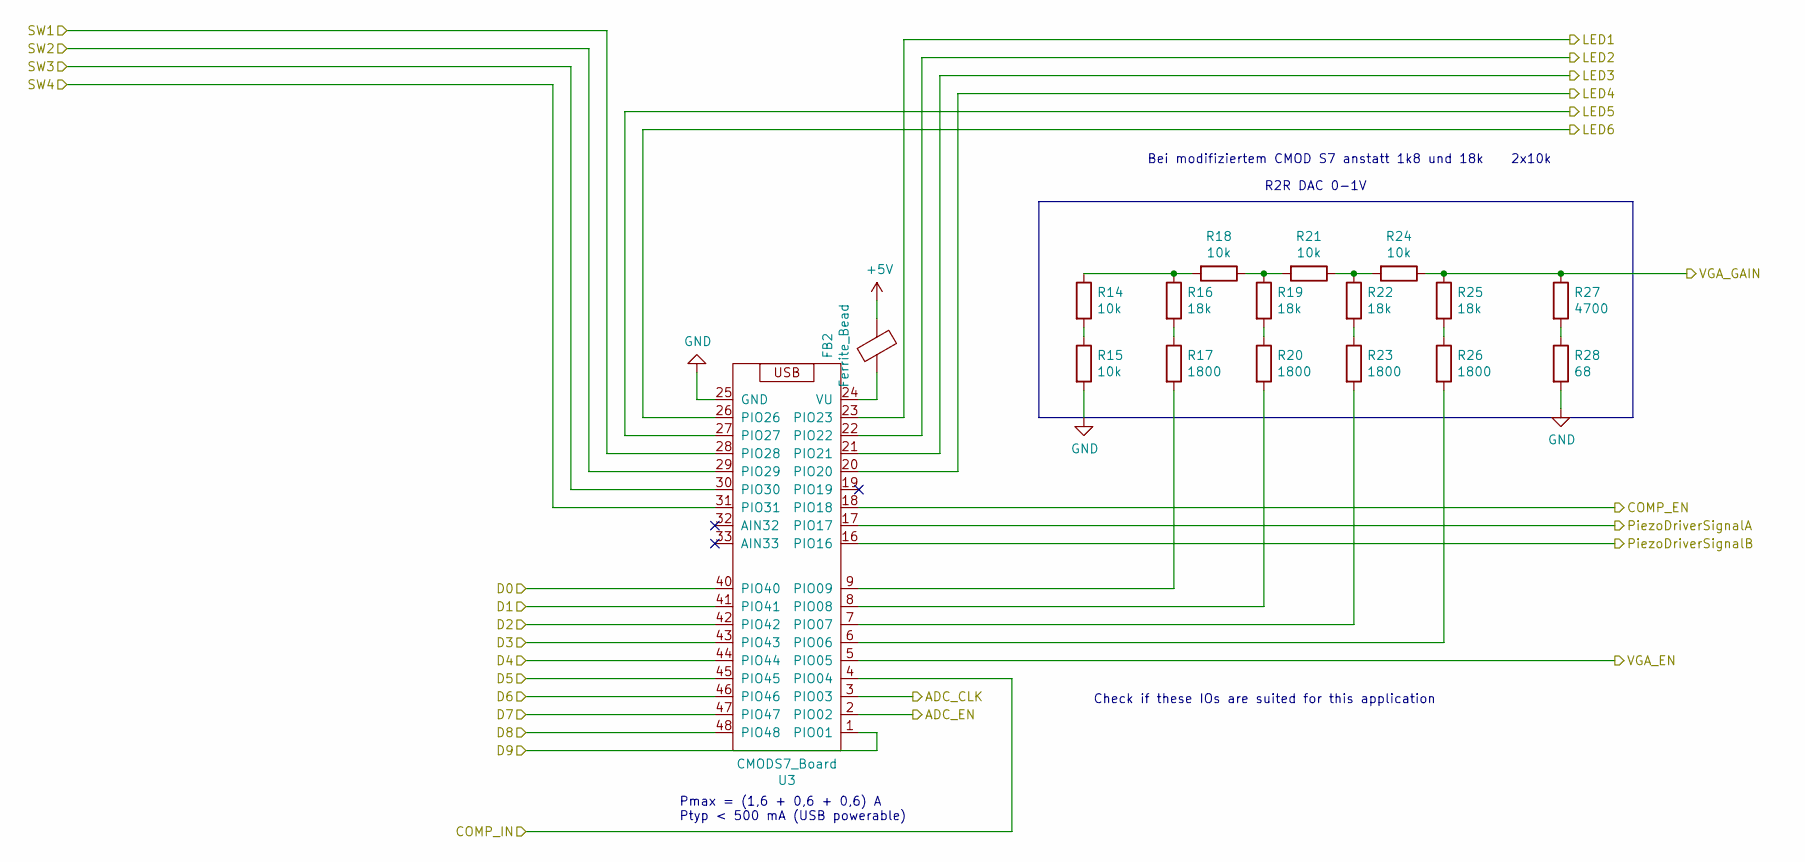
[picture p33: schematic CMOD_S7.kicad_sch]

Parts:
FB2: Ferrite_Bead; L_0603_1608Metric_Pad1.05x0.95mm_HandSolder
R14, R15, R18, R21, R24: 10k; R_0603_1608Metric_Pad0.98x0.95mm_HandSolder
R16, R19, R22, R25: 18k; R_0603_1608Metric_Pad0.98x0.95mm_HandSolder
R17, R20, R23, R26: 1800; R_0603_1608Metric_Pad0.98x0.95mm_HandSolder
R27: 4700; R_0603_1608Metric_Pad0.98x0.95mm_HandSolder
R28: 68; R_0603_1608Metric_Pad0.98x0.95mm_HandSolder
U3: CMODS7_Board; CMOD_S7_Socket

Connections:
+5V: FB2.2; also elsewhere on the board
/CMOD_S7/ADC_CLK: U3.3 (PIO03); also elsewhere on the board
/CMOD_S7/ADC_EN: U3.2 (PIO02); also elsewhere on the board
/CMOD_S7/COMP_EN: U3.18 (PIO18); also elsewhere on the board
/CMOD_S7/COMP_IN: U3.4 (PIO04); also elsewhere on the board
/CMOD_S7/D0: U3.40 (PIO40); also elsewhere on the board
/CMOD_S7/D1: U3.41 (PIO41); also elsewhere on the board
/CMOD_S7/D2: U3.42 (PIO42); also elsewhere on the board
/CMOD_S7/D3: U3.43 (PIO43); also elsewhere on the board
/CMOD_S7/D4: U3.44 (PIO44); also elsewhere on the board
/CMOD_S7/D5: U3.45 (PIO45); also elsewhere on the board
/CMOD_S7/D6: U3.46 (PIO46); also elsewhere on the board
/CMOD_S7/D7: U3.47 (PIO47); also elsewhere on the board
/CMOD_S7/D8: U3.48 (PIO48); also elsewhere on the board
/CMOD_S7/D9: U3.1 (PIO01); also elsewhere on the board
/CMOD_S7/LED1: U3.23 (PIO23); also elsewhere on the board
/CMOD_S7/LED2: U3.22 (PIO22); also elsewhere on the board
/CMOD_S7/LED3: U3.21 (PIO21); also elsewhere on the board
/CMOD_S7/LED4: U3.20 (PIO20); also elsewhere on the board
/CMOD_S7/LED5: U3.27 (PIO27); also elsewhere on the board
/CMOD_S7/LED6: U3.26 (PIO26); also elsewhere on the board
/CMOD_S7/PiezoDriverSignalA: U3.17 (PIO17); also elsewhere on the board
/CMOD_S7/PiezoDriverSignalB: U3.16 (PIO16); also elsewhere on the board
/CMOD_S7/SW1: U3.28 (PIO28); also elsewhere on the board
/CMOD_S7/SW2: U3.29 (PIO29); also elsewhere on the board
/CMOD_S7/SW3: U3.30 (PIO30); also elsewhere on the board
/CMOD_S7/SW4: U3.31 (PIO31); also elsewhere on the board
/CMOD_S7/VGA_EN: U3.5 (PIO05); also elsewhere on the board
/CMOD_S7/VGA_GAIN: R24.1, R25.1, R27.1; also elsewhere on the board
GND: R15.2, R28.2, U3.25 (GND); also elsewhere on the board
unnamed: FB2.1, U3.24 (VU)
unnamed: R14.1, R16.1, R18.2
unnamed: R14.2, R15.1
unnamed: R16.2, R17.1
unnamed: R17.2, U3.9 (PIO09)
unnamed: R18.1, R19.1, R21.2
unnamed: R19.2, R20.1
unnamed: R20.2, U3.8 (PIO08)
unnamed: R21.1, R22.1, R24.2
unnamed: R22.2, R23.1
unnamed: R23.2, U3.7 (PIO07)
unnamed: R25.2, R26.1
unnamed: R26.2, U3.6 (PIO06)
unnamed: R27.2, R28.1

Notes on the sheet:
Pmax = (1,6 + 0,6 + 0,6) A Ptyp < 500 mA (USB powerable)
R2R DAC 0-1V
Check if these IOs are suited for this application
Bei modifiziertem CMOD S7 anstatt 1k8 und 18k 2x10k

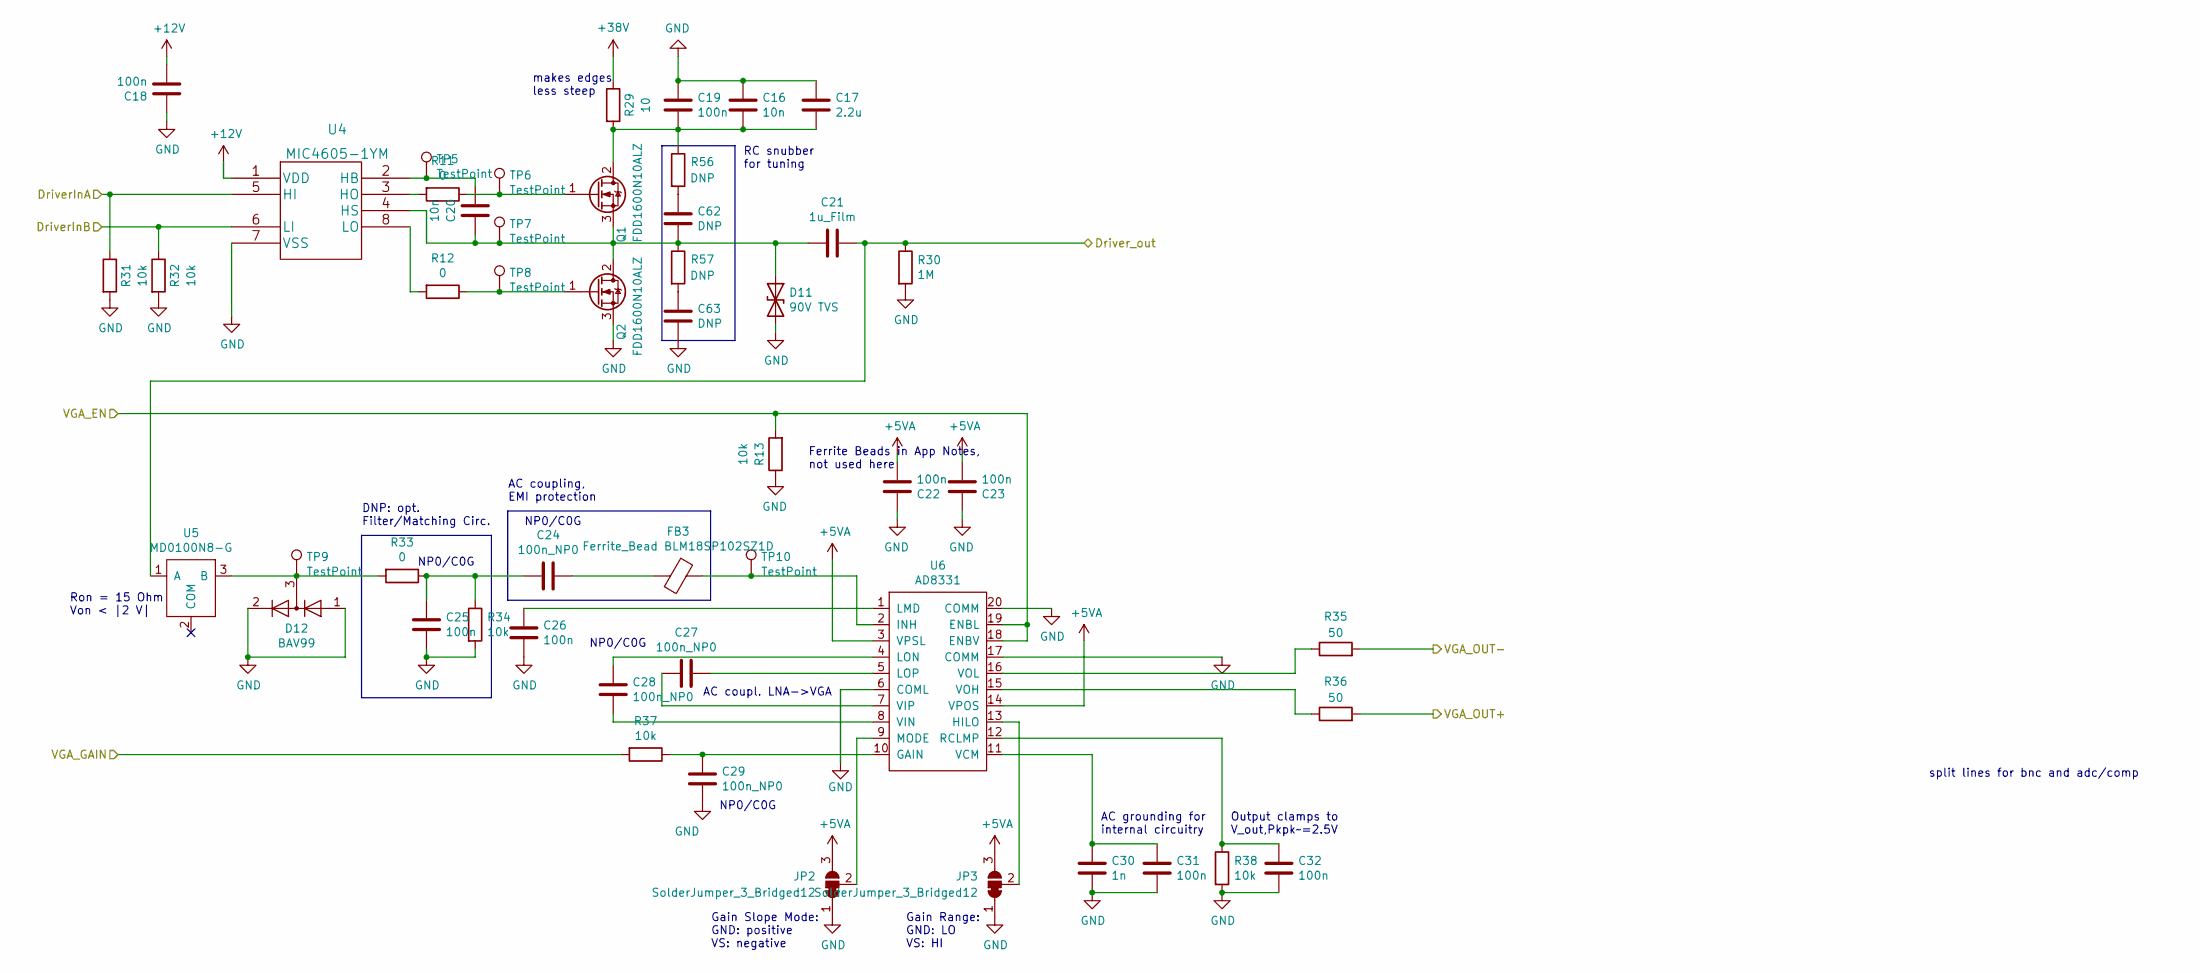
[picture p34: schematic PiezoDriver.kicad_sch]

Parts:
C16, C20: 10n; C_0603_1608Metric_Pad1.08x0.95mm_HandSolder
C17: 2.2u; C_1206_3216Metric_Pad1.33x1.80mm_HandSolder
C18, C19, C22, C23, C25, C26, C31, C32: 100n; C_0603_1608Metric_Pad1.08x0.95mm_HandSolder
C21: 1u_Film; C_2824_7260Metric_HandSolder
C24, C27, C28, C29: 100n_NP0; C_1206_3216Metric_Pad1.33x1.80mm_HandSolder
C30: 1n; C_0603_1608Metric_Pad1.08x0.95mm_HandSolder
C62, C63: DNP; C_0603_1608Metric_Pad1.08x0.95mm_HandSolder
D11: 90V TVS; D_SMA_Handsoldering
D12: BAV99; SOT-23
FB3: Ferrite_Bead BLM18SP102SZ1D; L_0603_1608Metric_Pad1.05x0.95mm_HandSolder
JP2, JP3: SolderJumper_3_Bridged12; SolderJumper-3_P1.3mm_Bridged12_RoundedPad1.0x1.5mm
Q1, Q2: FDD1600N10ALZ; TO-252-2
R11, R12, R33: 0; R_0603_1608Metric_Pad0.98x0.95mm_HandSolder
R13, R31, R32, R34, R37, R38: 10k; R_0603_1608Metric_Pad0.98x0.95mm_HandSolder
R29: 10; R_0603_1608Metric_Pad0.98x0.95mm_HandSolder
R30: 1M; R_0603_1608Metric_Pad0.98x0.95mm_HandSolder
R35, R36: 50; R_0603_1608Metric_Pad0.98x0.95mm_HandSolder
R56, R57: DNP; R_0603_1608Metric_Pad0.98x0.95mm_HandSolder
TP5, TP6, TP7, TP8, TP9, TP10: TestPoint; TestPoint_Loop_D1.80mm_Drill1.0mm_Beaded
U4: MIC4605-1YM; SOIC-8_3.9x4.9mm_P1.27mm
U5: MD0100N8-G; SOT-89-3_Handsoldering
U6: AD8331; QSOP-20_3.9x8.7mm_P0.635mm

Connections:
+5VA: C22.2, C23.2, JP2.3 (B), JP3.3 (B), U6.3 (VPSL), U6.14 (VPOS); also elsewhere on the board
+12V: C18.2, U4.1 (VDD); also elsewhere on the board
+38V: R29.1; also elsewhere on the board
/CMOD_S7/PiezoDriverSignalA: R31.1, U4.5 (HI); also elsewhere on the board
/CMOD_S7/PiezoDriverSignalB: R32.1, U4.6 (LI); also elsewhere on the board
/CMOD_S7/VGA_EN: R13.2, U6.18 (ENBV), U6.19 (ENBL); also elsewhere on the board
/CMOD_S7/VGA_GAIN: R37.2; also elsewhere on the board
/PiezoDriver/Driver_out: C21.1, R30.1, U5.1 (A); also elsewhere on the board
/PiezoDriver/VGA_OUT+: R36.2; also elsewhere on the board
/PiezoDriver/VGA_OUT-: R35.2; also elsewhere on the board
GND: C16.1, C17.1, C18.1, C19.1, C22.1, C23.1, C25.2, C26.2, C29.2, C30.2, C31.2, C32.2, C63.2, D11.2 (A2), D12.1 (K), D12.2 (A), JP2.1 (A), JP3.1 (A), Q2.3 (S), R13.1, R30.2, R31.2, R32.2, R34.2, R38.2, U4.7 (VSS), U6.6 (COML), U6.17 (COMM), U6.20 (COMM); also elsewhere on the board
unnamed: C16.2, C17.2, C19.2, Q1.2 (D), R29.2, R56.1
unnamed: C20.1, C21.2, C62.2, D11.1 (A1), Q1.3 (S), Q2.2 (D), R57.1, TP7.1, U4.4 (HS)
unnamed: C20.2, TP5.1, U4.2 (HB)
unnamed: C24.1, FB3.2
unnamed: C24.2, C25.1, R33.1, R34.1
unnamed: C26.1, U6.1 (LMD)
unnamed: C27.1, U6.5 (LOP)
unnamed: C27.2, U6.7 (VIP)
unnamed: C28.1, U6.8 (VIN)
unnamed: C28.2, U6.4 (LON)
unnamed: C29.1, R37.1, U6.10 (GAIN)
unnamed: C30.1, C31.1, U6.11 (VCM)
unnamed: C32.1, R38.1, U6.12 (RCLMP)
unnamed: C62.1, R56.2
unnamed: C63.1, R57.2
unnamed: D12.3 (K), R33.2, TP9.1, U5.3 (B)
unnamed: FB3.1, TP10.1, U6.2 (INH)
unnamed: JP2.2 (C), U6.9 (MODE)
unnamed: JP3.2 (C), U6.13 (HILO)
unnamed: Q1.1 (G), R11.1, TP6.1
unnamed: Q2.1 (G), R12.1, TP8.1
unnamed: R11.2, U4.3 (HO)
unnamed: R12.2, U4.8 (LO)
unnamed: R35.1, U6.16 (VOL)
unnamed: R36.1, U6.15 (VOH)

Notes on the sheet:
makes edges less steep
NP0/C0G
Ron = 15 Ohm Von < |2 V|
AC grounding for internal circuitry
AC coupling, EMI protection
split lines for bnc and adc/comp
Output clamps to V_out,Pkpk~=2.5V
Gain Slope Mode: GND: positive VS: negative
Gain Range: GND: LO VS: HI
AC coupl. LNA->VGA
RC snubber for tuning
DNP: opt. Filter/Matching Circ.
Ferrite Beads in App Notes, not used here

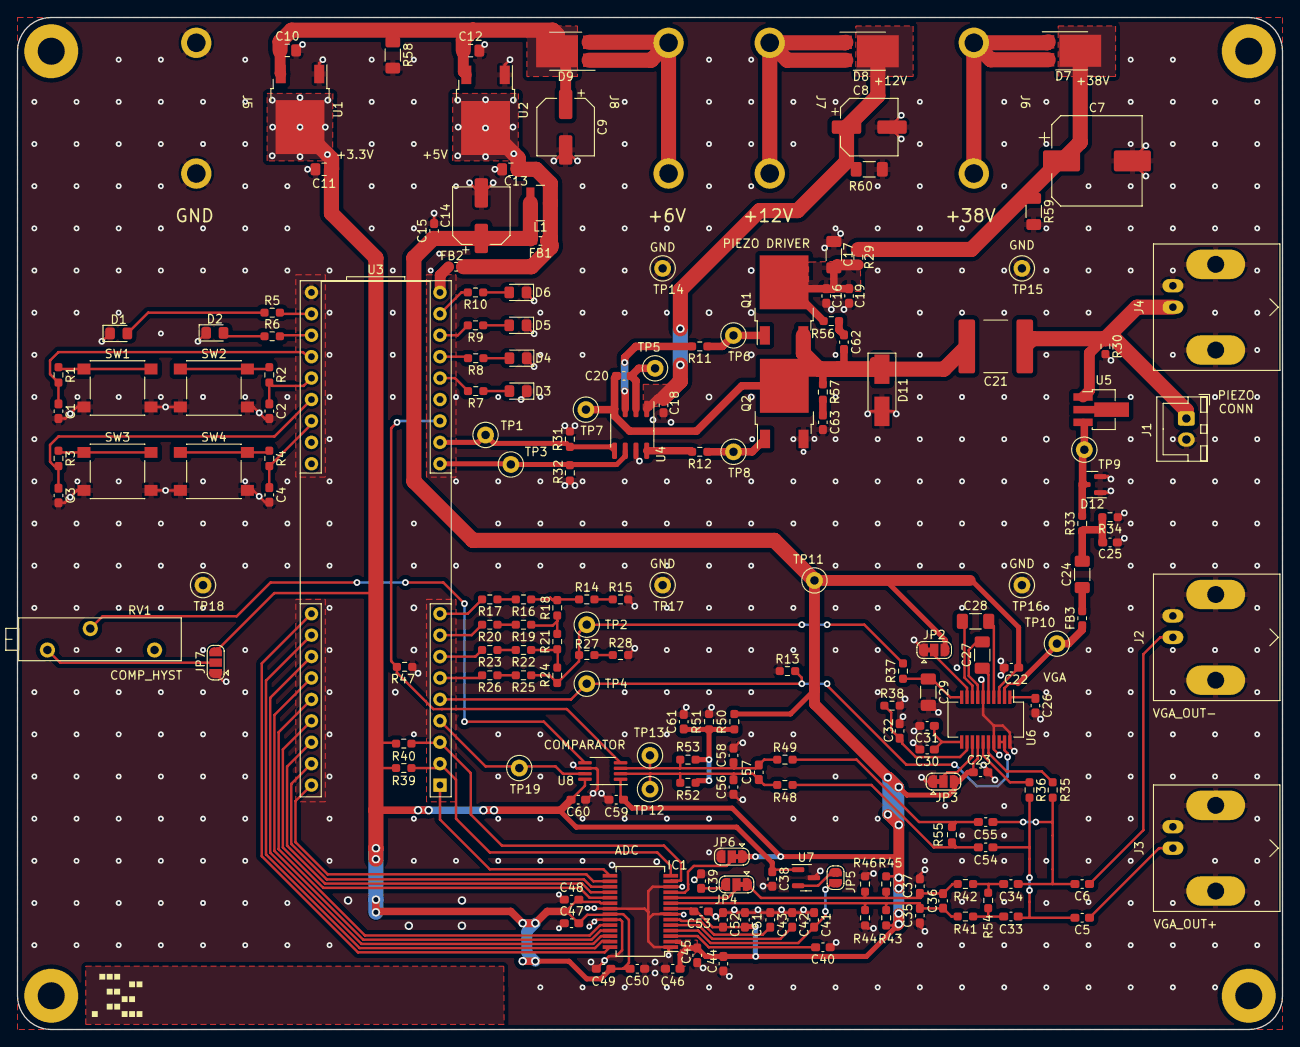
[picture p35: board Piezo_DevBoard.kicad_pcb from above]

Board: 2 copper layers, 150.0 x 120.0 mm, 188 parts (0 on the bottom side), 111 nets.

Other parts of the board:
J1001: eurocard_extended

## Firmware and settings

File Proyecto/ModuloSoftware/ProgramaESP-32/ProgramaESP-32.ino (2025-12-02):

#include "BluetoothSerial.h"

// CONFIG GENERAL
BluetoothSerial SerialBT;

void setup() {
  pinMode(26, OUTPUT);                      // Inicializar el pin de conmutación
  Serial.begin(9600);                       // Inicializar la comunicación serial
  
  SerialBT.begin("ESP32_ECOAQUA"); // Nombre Bluetooth

  Serial.println("Bluetooth listo: ESP32_ECOAQUA");
}

void loop() {
  float r = resistance();         // Medir resistencia
  float ph = ph_obtain();
  float temp = temp_obtain();
  float turb = turb_obtain();
  float diso = do_obtain(); 

  Serial.println("===== ECOAQUA =====");

  Serial.println();               // Imprimir resistencia
  
  Serial.print("PH: ");
  Serial.println(ph);

  Serial.print("Turbidez: ");
  Serial.println(turb, 4);
  
  Serial.print("Temperatura: ");
  Serial.println(temp, 4);

  Serial.print("Resistencia: ");
  Serial.println(r);

  Serial.print("O2 disuelto: "); 
  Serial.println(diso, 4);

  String paquete =
      String(ph, 2) + "," +
      String(turb, 2) + "," +
      String(temp, 2) + "," +
      String(r, 2) + "," +
      String(diso, 2);

  SerialBT.println(paquete);   // Enviar paquete a App Inventor

  Serial.print("TX: ");        // Mostrar lo enviado
  Serial.println(paquete);

  delay(1000);                    // Delay en escritura
}

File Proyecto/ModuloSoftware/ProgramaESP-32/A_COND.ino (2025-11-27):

int r2 = 100;                               // Constante r1 para el cálculo de resistencia
float cond_gain = 11;                       // Ganancia del amplificador del sensor de conductividad

float resistance(){
  float ref_v = 0;                          // Definir valores iniciales
  float read_v = 0;
  float pulse_v = 0;
  float vin = 0;
  float vout = 0;
  float r1 = 0;
  float sum = 0;

  int counter = 0;
  while(counter != 1000){
    digitalWrite(26, HIGH);                 // Conmutar en alto
    delayMicroseconds(250);                 // Delay en semiciclo

    ref_v = 3.3 * analogRead(33) / 4096;    // Voltaje de referencia
    read_v = 3.3 * analogRead(25) / 4096;   // Voltaje leído con amplificación respecto a referencia
    pulse_v = 3.3 * analogRead(32) / 4096;  // Voltaje de pulso conmutado
    vin = pulse_v - ref_v;                  // Obtener voltaje de entrada del divisor
    vout = (read_v - ref_v) / cond_gain;    // Obtener voltaje de salida del divisor deshaciendo la amplificación
    r1 = ((vin * r2)/vout) - r2;            // Conociendo la resistencia inferior (r2) calcular r1
    sum = sum + r1;                         // Sumar para promediar las lecturas

    digitalWrite(26, LOW);                  // Conmutar en bajo
    delayMicroseconds(250);                 // Delay en semiciclo

    counter = counter + 1;
  }
  sum = sum / 1000;                         // Promediar las lecturas de las 1000 muestras
  return sum;                               // Retornar
}

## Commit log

2025-08-21 Create Archivo de prueba.txt
2025-09-03 ESQUEMÁTICO-KICAD
    SOLO DIBUJO BURDO - Muy posible que se use EasyEDA. Estoy más familiarizado con KiCAD
    [Medidor-Q.kicad_pcb, Medidor-Q.kicad_sch]
2025-10-15 Estructura de funciones
2025-10-23 Actualización(23-10)
    [Matriz morfológica y evaluación.xlsx]
2025-10-23 ACTUALIZACIÓN 23-10 (3)
    [Evaluación matriz morfológica (1).xlsx]
2025-11-14 Actualización 1
    HABRÁ MAYOR DOCUMENTACIÓN DE SENSORES
    [schematic.kicad_pcb, schematic.kicad_sch]
2025-11-27 Actualización de archivos
    [Medidor-Q.kicad_pcb, Medidor-Q.kicad_sch, schematic.kicad_pcb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]
2025-11-27 Update Diagrama de flujo.txt
2025-11-27 Update and rename Diagrama de flujo.txt to Diagrama de flujo.md
2025-11-27 Update Diagrama de flujo.md
